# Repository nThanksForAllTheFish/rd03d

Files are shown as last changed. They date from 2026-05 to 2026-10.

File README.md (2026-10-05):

# RD-03D stair radar

A 24 GHz radar in a 3D-printed case watches a staircase and turns the light on before anyone reaches the first step, then off a minute after they are gone. The sensor is an Ai-Thinker RD-03D, the controller a Seeed XIAO ESP32-C6, the automation a four-node Node-RED flow. Nearly all of the firmware, the web chart, the flow and the enclosure CAD were written by an AI agent over four weeks of evenings, with the CAD built by driving a live Fusion 360 session through its scripting API. The write-up below is about how that went, and about the places where the reviewing human earned his keep.

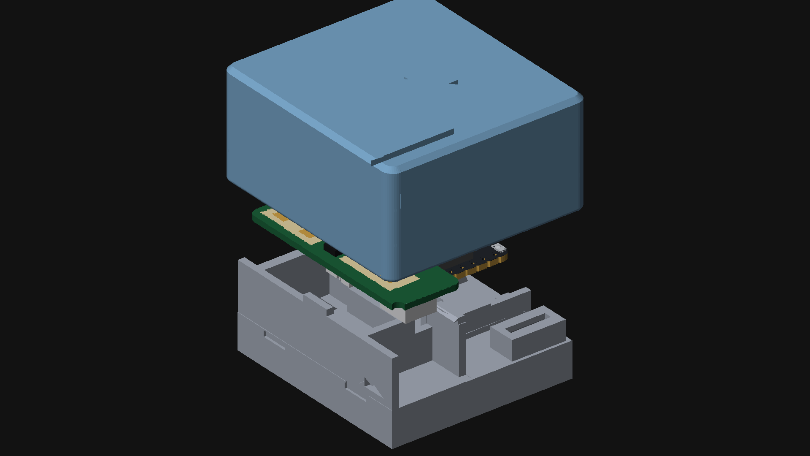
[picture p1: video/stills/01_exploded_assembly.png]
Exploded view: back plate, RD-03D and XIAO, front shell


## What is in this repository

| Path | What it is |
| --- | --- |
| `rd03d_uart/` | ESP-IDF firmware for the XIAO ESP32-C6: radar frame parser, live browser chart over WebSocket, MQTT events, OTA with rollback, station and access-point images. Host-side unit tests in `tests/`. |
| `case/` | The two-part snap-fit case: STLs ready to print, and the numbered Fusion 360 Python scripts that are the actual design, plus the read-only geometric probe harness `90_verify.py`. |
| `node-red/` | The stair-light flow, a validator, and an MQTT acceptance test. |
| `RD03D_RadarChart/` | The original Processing visualiser for the sensor over USB serial, kept for reference. |
| `docs/superpowers/` | The ten dated design specs and implementation plans the agent worked from, in the order they were written. |
| `video/` | The pipeline that synthesised the project video: frame generator, narration, STEP-to-mesh converter, and the rendered figures used below. |

Each of the first three directories has its own README with the details. The rest of this page is the quick start and the story.

## Quick start

Wire the radar to the XIAO: radar TX to D7 (GPIO17), radar RX to D6 (GPIO16), 5 V and GND. The radar UART runs at 256000 baud, 8N1.

Build and flash with ESP-IDF v5.5. The WiFi SSID and password live only in the untracked `sdkconfig`, set through `idf.py menuconfig` under *RD03D Configuration*.

```bash
cd rd03d_uart
idf.py set-target esp32c6
idf.py menuconfig          # RD03D Configuration: WiFi SSID / password, MQTT broker
idf.py build
idf.py -p /dev/cu.usbmodemXXXX flash monitor
```

Open `http://rd03d.local` on the same network for the live chart. After the first USB flash, updates go over WiFi and roll back by themselves if the new image fails to come up within 90 s:

```bash
idf.py build && curl -X POST --data-binary @build/rd03d_uart.bin http://rd03d.local/update
```

For a site where the device cannot join the WiFi, build the access-point image instead. It brings up its own network, `rd03d-radar`, serves the chart at `http://192.168.4.1`, and compiles MQTT out:

```bash
idf.py -B build.ap -D SDKCONFIG=sdkconfig.ap build
```

The station image publishes `rd03d/target/1..3` as `{"x","y","v"}` in millimetres and centimetres per second whenever a target appears or has moved more than 200 mm, `{"gone":true}` when it leaves, and a retained `rd03d/status` of `online` or `offline`. Import `node-red/flows-stair-light.json` into Node-RED, change the relay topic in the node marked *EDIT DEVICE*, tune the zone in the node marked *EDIT ZONE* using the chart, and deploy. `node-red/test_stair_flow.py` exercises the flow with synthetic events.

Print the case in PETG, 0.2 mm layers, no supports, with the shell at high infill so the radome in front of the antennas is solid plastic. Fit the USB-C jack before the boards. The six holes in the back are LEGO Technic pitch, for a ball-joint mount. The full assembly order, including why the jack goes in from the back and is soldered afterwards, is in `case/README.md`.

The host tests need nothing but a C compiler:

```bash
cd rd03d_uart/tests
cc -Wall -Wextra -o test_rd03d test_rd03d.c ../main/rd03d.c && ./test_rd03d
cc -Wall -Wextra -o test_mqtt_throttle test_mqtt_throttle.c ../main/mqtt_throttle.c && ./test_mqtt_throttle
```

## A radar stair light, built with an AI co-engineer

The gadget is a weekend's work for anyone reading this and not worth an article. What is worth an article is that over four weeks of evenings, from the end of August to late September, an AI agent wrote essentially all of the firmware, the web interface, the home-automation flow, and the CAD for the enclosure, and that the CAD was done by driving my own copy of Fusion 360 directly rather than by emitting a file for me to import. My job turned into something closer to a reviewing engineer and lab tech than a designer, and I caught the agent out often enough that the review was not a formality. I think the shape of that collaboration maps directly onto any one-off hardware build: the bracket, the jig, the sensor-in-a-box that most of us design once and never document.

### What got built

The sensor is an Ai-Thinker RD-03D, a 24 GHz FMCW module with one transmit patch pair and a 2×2 receive array that tracks up to three targets and spits out x, y and radial velocity over a 256 kbaud UART, thirty bytes per frame. It is wired to a Seeed XIAO ESP32-C6, a thumbnail-sized RISC-V board with 2.4 GHz WiFi. The firmware is ESP-IDF, about 1,450 lines of C including the host tests. It parses the radar frames, serves a live radar plot in a browser at a local mDNS name over a WebSocket at about 11 Hz, publishes target events over MQTT to a Mosquitto broker, takes over-the-air firmware updates with automatic rollback if a new image fails to come up, and can be built as a second variant that is its own WiFi access point with MQTT compiled out, for places where you cannot put a stray device on the network. A Node-RED flow on a Raspberry Pi subscribes to the target topics, applies a zone filter, holds the light on with a retriggerable 60 s timer and drives a Tasmota relay.

The enclosure is a two-part snap-fit case: an 8 mm back plate carrying the radar bay, the XIAO posts, five cantilever retention clips, a USB-C power jack with its decoupling capacitor cradled inside, and six LEGO Technic pin holes on 8 mm pitch so the whole thing hangs off a Technic ball joint for aim adjustment. The front shell has a thinned radome step over the antennas and a hold-down boss over the XIAO's RF can. It printed in PETG on a 0.6 mm nozzle with no supports, after seven revisions of the plate.

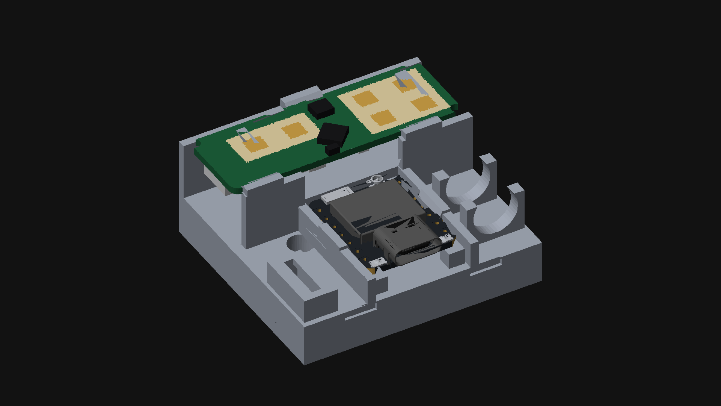
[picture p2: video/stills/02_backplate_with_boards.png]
Back plate with both boards seated


### How the firmware side went

The working pattern was the same for every feature. I described what I wanted in a paragraph. The agent wrote a short design spec, I read it and argued with it, then it wrote a numbered implementation plan and executed it, testing as it went. Ten of those spec-and-plan pairs are in `docs/superpowers/`, dated, and they read like a lab notebook. The UART reader came first, with the frame parser written as plain C and unit-tested on the Mac before it ever touched the board. The WiFi web chart came next, then OTA, then MQTT, then the Node-RED flow, then the access-point variant, each as a branch merged after a hardware check.

The useful discipline here was that the agent insisted on testable seams. The radar parser and the MQTT throttling logic, which decides that a target has to move 200 mm before a new event is worth publishing, are pure functions with nineteen host-side tests between them. The OTA path got a deliberate drill: we flashed an image that was built to fail, watched it boot, fail to bring up its web server inside the 90 s window, and roll itself back to the previous image in about 95 s. The browser-side verification was equally direct. The agent opened the chart in a browser, walked the WebSocket, and read the HUD back to confirm the firmware version it had just flashed.

It also walked into the kind of traps that any of us would have, and had to dig out. Two examples. The ESP-IDF web server does not call your URI handler during a WebSocket handshake, so the client-tracking pattern in the first draft was dead code, and clients had to be enumerated from the server's own list instead. More subtly, the access-point variant kept rolling back after every OTA while USB flashing worked fine. The rollback-cancel was gated on "we have an IP address", and in AP mode no IP event ever fires. The fix was one line. Finding it was an evening. None of this is a criticism of the tool so much as a reminder that it is doing real engineering with the same documentation we have, and the documentation lies in the same places.

### How the CAD side went, which is the part I want you to see

The enclosure was not designed by generating a mesh. Autodesk ships a Model Context Protocol server for Fusion 360, which is a small local HTTP endpoint that lets an agent run Python against the live Fusion API inside your open document. The agent wrote a driver that speaks that protocol, `case/fusion_scripts/run_fusion.py`, then built the case as a sequence of numbered Python scripts: set up user parameters, build the back plate, build the shell, place reference bodies for the two boards, export STLs. About 1,900 lines of Python in all, and those scripts are the design. Every feature in the plate, every clip, ramp, counterbore and wire notch, is a few lines in a script that reads like a construction record, with the dimension and the reason next to each other. When something had to change, the agent edited the script and re-ran it, and Fusion rebuilt the body. I watched it happen in the Fusion window.

Two things about this were new to me. The first is that a scripted design is reviewable in the way code is reviewable. I could read a diff and see that a rib had moved from x 3.0 to x 5.6 and why. Try doing that with a feature tree. The second is that the agent wrote itself a verification harness. The last script in the sequence, `90_verify.py`, is read-only: it probes the finished bodies with point-containment queries, asking Fusion "is there material at this coordinate" at a few dozen points, and asserts that the walls are where the spec says, that the counterbores are open, that the USB jack slot is clear, that a rib is not roofing a LEGO bore. It caught exactly that last one, a capacitor rib placed over a pin hole, before I printed it. That is a unit test for a mechanical part, and I had never seen one.

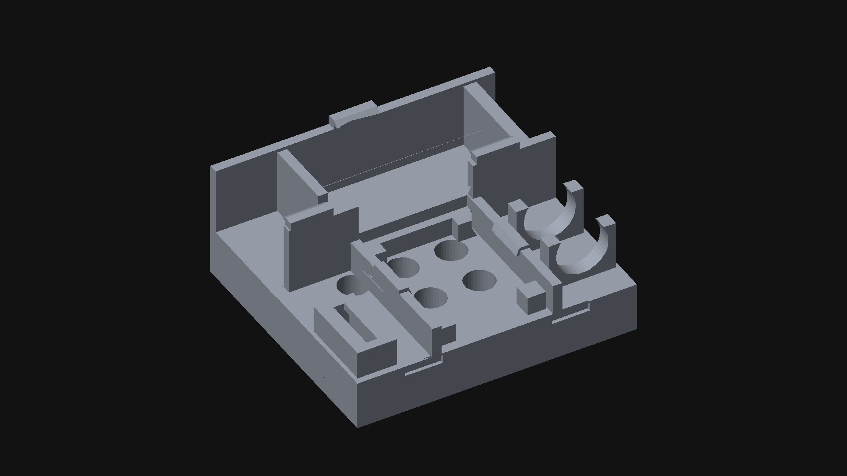
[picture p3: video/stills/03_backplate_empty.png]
Empty back plate: crossbars, clips, jack slot and capacitor cradle


### Where the human earned his keep

The honest part of the story is the list of things the agent got confidently wrong and I caught, usually by holding the printed part or staring at the Fusion model. I am including it because it is the real argument for this way of working: the agent is fast and tireless and does not know what it does not know, and a reviewing engineer who does is the thing that makes the pair better than either alone.

The board was resting on its connector. The agent had sized the crossbars under the radar PCB from the board's overall thickness, which includes a 5-pin connector that protrudes rearward. The bare PCB back is actually 3.8 mm further in. So as designed the radar sat on its connector and nothing else. I spotted that in the Fusion model; the agent then probed the vendor's board model, found two component-free bands, and moved the crossbars to bear on bare PCB with the connector hanging free between them.

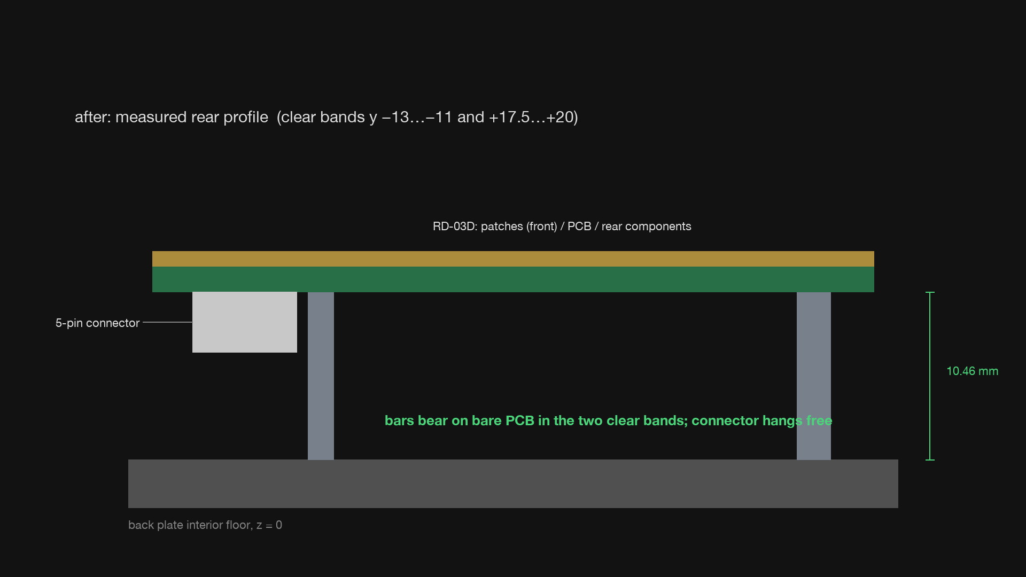
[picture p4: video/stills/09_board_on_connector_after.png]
Before and after: the board on its connector, then on the crossbars


The radome was tuned to the worst possible gap. This one is the physics lesson, and I want to spell it out. At 24 GHz the free-space wavelength is λ = c/f = 12.5 mm. The agent had, several times, assured me the air gap between the antenna face and the inside of the radome was about 1 mm. It had anchored that number on the top of the board's bounding box, which is the tallest IC, not the antenna plane. The true antenna-to-radome gap, after a well-meaning change that moved the window pocket to the inside face, was 3.1 mm. A quarter wavelength is λ/4 = 3.125 mm. A quarter-wave gap is the anti-resonance case: the wave reflected off the radome's inner surface travels an extra half wavelength out and back, picks up the phase flip at the plastic boundary, and arrives back at the antenna in phase with the transmitted wave, which is the maximum possible mismatch. It is the same reason an anti-reflection coating is a quarter wave thick, run backwards. The rule I gave the agent and it then designed to was to keep the gap under λ/10, about 1.25 mm, where the reflected field has not had room to rotate far. The fix brought the radome down to a 1.21 mm gap over both antenna groups, with the plastic in front of them a solid 3.1 mm, and the exterior face stays flat. I would not have caught this from the script. I caught it from a section view.

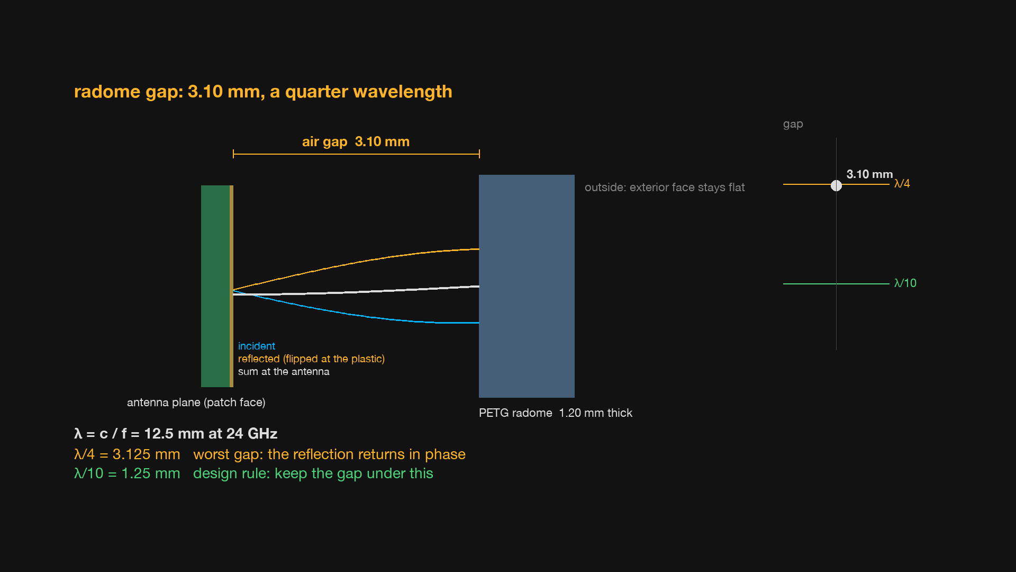
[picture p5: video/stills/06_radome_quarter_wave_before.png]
The radome gap at a quarter wavelength


The antenna was going in sideways. The two receive channels that give the module its angle measurement are spaced across the board's short axis, about λ/2 apart. That means the wide ±60° field of view opens across the board's width, and the beam is narrow along its length. I had assumed the opposite. For a staircase, where the sensor must tell an upstairs approach from a downstairs one, the fan has to be vertical, so the board mounts landscape. This was a fifteen-second conversation once the antenna geometry was on the table, and the kind of thing anyone who has laid out a patch array would catch before coffee.

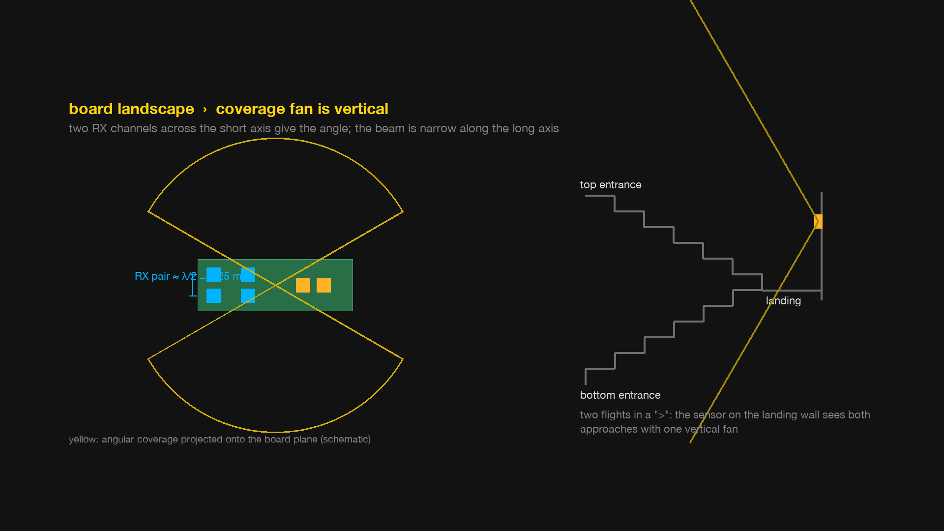
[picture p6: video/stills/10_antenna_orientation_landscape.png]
Antenna orientation: the fan opens across the board's width


The printer disagreed with the design. The first plate design had 0.6 mm fence walls and a shallow tape recess on the back face. I print with a 0.6 mm nozzle, so a 0.6 mm wall is at best one wobbly extrusion, and the recess meant the first layer was a thin rim with nothing in the middle. Both came out. All walls are now at least 1.5 mm, and the back is one flat face. Later the agent designed the XIAO clips as slender slotted fingers with the root trenched below the floor to keep bending strain near two percent in PETG, which is correct and which held the board about as firmly as a wet noodle. The slots and trenches came out and the clip is now a plain stretch of the 1.5 mm wall with a 0.6 mm lip. It takes a firm push to click the board in. That is fine. The agent's analysis was right about strain and wrong about what "holds" means to a thumb.

And the diagnosis that cost an hour: curl to the device's mDNS name hung every time while a browser worked. The device advertises an IPv6 link-local address over mDNS that is not routable from the Mac, curl tries it first and waits out its timeout. Forcing IPv4 fixes it. Not a device fault at all, and the agent and I both chased ghosts in the firmware before checking.

### What this means for your next part

Most of what gets printed in a home shop is a one-off: a bracket for a sensor, a jig to hold a board while you solder it, a mount for a camera, a box for the thing you just built. The loop I ran here, which is describe the part, have the agent build it parametrically in Fusion with a probe harness, print it, hold it, correct it, re-run the script, is the loop we already run with a human at the keyboard, only the keyboard part now takes minutes instead of an afternoon and leaves a reviewable script behind it. A part designed this way comes with its construction rationale and its own geometric self-test, and you, or anyone who forks this repo, can re-run it with a different board outline next year. None of this depends on Fusion. Any CAD package with a scripting API can be driven the same way: FreeCAD and OpenSCAD are scripting-native, Onshape has a REST API, and SolidWorks has a mature COM automation interface that is if anything an easier target than Fusion's.

The firmware side is the same story. A sensor on a serial port that logs to a broker and shows a live plot in a browser is exactly the sort of thing we build for a weekend project and then never document. Here the spec, the plan, the tests and the OTA path came along for free, because the agent will not skip them unless you tell it to.

Three cautions, briefly. First, the agent's confidence is uncorrelated with its correctness on anything it cannot measure, which in CAD is everything. Every print I did without a section view first was a print I did twice. Second, the physics still has to come from somewhere, and in this project it came from me and from the datasheet. The λ/4 mistake would have shipped. Third, treat the scripts, not the live CAD document, as the source of truth, and keep them under version control. The one time I let the agent tune a parameter in the Fusion UI instead of the script, the next re-run of the setup script silently reset it.

## Parts

- Ai-Thinker RD-03D 24 GHz radar module
- Seeed Studio XIAO ESP32-C6
- USB-C receptacle breakout with 5.1 kΩ CC pull-downs, 100 µF capacitor
- Raspberry Pi running Mosquitto and Node-RED
- Tasmota-flashed relay or smart plug
- PETG filament, 0.6 mm nozzle, no supports, shell at high infill so the radome is solid plastic
- Six LEGO Technic pins and a ball-joint arm for mounting

## Video

A synthesised walkthrough of the project, rendered from the STLs, the vendor board models and the real source files in this repository, is on YouTube: https://youtu.be/SwnVpzrGE3c. The video's script, this README and the write-up above were drafted by the AI agent (Claude Code), then reviewed and corrected by the author. The pipeline that produced the video is in `video/`; the board STEP models it uses are third-party downloads and are not redistributed here.

## Licence

Code is MIT (`LICENSE`). The write-up, documents, STL files and figures are CC BY 4.0 (`LICENSE-CC-BY-4.0.md`).

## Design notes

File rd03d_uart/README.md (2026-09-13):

# rd03d_uart

XIAO ESP32-C6 firmware that reads an Ai-Thinker RD-03D 24GHz mmWave radar over
UART1, prints decoded targets to the USB-C serial console, and serves a live
radar chart over WiFi.

The tree builds two images from the same sources:

| | Station (default) | Access point |
| --- | --- | --- |
| WiFi | joins an existing 2.4 GHz WPA2 network | is its own WPA2 access point |
| Chart at | http://rd03d.local | http://192.168.4.1 |
| MQTT | published | compiled out |
| Build dir | `build/` | `build.ap/` |
| Config | `sdkconfig` | `sdkconfig.ap` |

Use the AP image where the device is not allowed onto the local WiFi — a work
site that only admits registered hardware, or anywhere there is no network to
join.

## Wiring

| RD-03D | XIAO ESP32-C6 |
| --- | --- |
| TX | D7 (GPIO17) |
| RX | D6 (GPIO16) |
| 5V | 5V |
| GND | GND |

Radar UART: 256000 baud, 8N1.

## Build & flash

Find the port rather than assuming it — boards enumerate differently, and a
second board plugged into the same Mac will not get the same number:

```bash
ls /dev/cu.usbmodem*
```

With more than one board attached, confirm which is which before flashing.

Station image (joins your WiFi):

```bash
source ~/esp/esp-idf-v5.5/export.sh
idf.py set-target esp32c6   # first time only
idf.py build
idf.py -p /dev/cu.usbmodemXXXX flash monitor
```

Access-point image:

```bash
source ~/esp/esp-idf-v5.5/export.sh
idf.py -B build.ap -D SDKCONFIG=sdkconfig.ap build
idf.py -B build.ap -D SDKCONFIG=sdkconfig.ap -p /dev/cu.usbmodemXXXX flash monitor
```

The two configurations never collide: each keeps its own build directory and
its own config file, so switching between them needs no clean and no
`set-target`.

### The config files hold the credentials, and git does not

`sdkconfig` holds the home/office network SSID and password. `sdkconfig.ap`
holds the SoftAP PSK. **Both are untracked and deliberately gitignored, so
neither is in any commit — delete one and the credentials in it are gone.**
Keep a copy somewhere outside the repo before doing anything drastic, and
never `rm` them to "get a clean build" (use a different `-B` directory
instead). Everything else in them regenerates from `idf.py menuconfig`
(*RD03D Configuration*); the passwords do not.

## Output

One line per radar frame (up to 3 targets), plus link stats every 5 s:

```
T1: x=-123mm y=456mm v=-12cm/s | T2: --- | T3: ---
I (5210) rd03d: link stats: dropped=0 bad_frames=0
```

`dropped` counts parser resync bytes only (not any UART driver-level loss);
`bad_frames` counts frames with a corrupt tail. Both should stay flat while a
monitor is attached.

Note that the USB-Serial-JTAG console does not reset the board when you attach,
so connecting late shows radar frames but no boot banner. Reset the board (or
use `idf.py monitor`, which resets for you) to see the startup log.

## Web UI

Either image serves the same live chart: targets on an XY plot with trails,
plus link stats.

- Data path: `GET /ws` WebSocket pushes one JSON message per radar frame,
  e.g. `{"t":[{"x":-551,"y":550,"v":0},null,null],"dropped":0,"bad":0}`
  (x/y in mm, v in cm/s, absent targets `null`).
- At boot the firmware puts the radar in multi-target mode itself; viewers
  never send radar commands.
- Untethered use: power the XIAO from a USB power bank; the USB console is
  optional diagnostics only.

### Station image

Joins the network configured in `idf.py menuconfig` (*RD03D Configuration* →
SSID/password, stored only in `sdkconfig`; 2.4 GHz WPA2 only). Open
**http://rd03d.local** from any browser on that network.

### Access-point image

The XIAO brings up its own network on boot; nothing else is required, and
there is no router, DHCP lease, or broker involved.

- SSID **`rd03d-radar`**. The PSK is not written down here — this file is
  tracked in git. It lives in `sdkconfig.ap` as `RD03D_AP_PASSWORD`, visible
  through `idf.py -B build.ap -D SDKCONFIG=sdkconfig.ap menuconfig`.
- Once joined, open **http://192.168.4.1**. mDNS is also registered, so
  **http://rd03d.local** usually works too — but 192.168.4.1 is the address
  that always works, so reach for it first when something seems wrong.
- **Joining the AP takes the laptop off its normal WiFi**, since a client can
  hold only one association at a time. Run the intranet over ethernet
  alongside it; macOS will use the wired interface for everything that is not
  192.168.4.x.
- The boot log confirms the AP is up:
  `wifi_link: softap up, ssid=rd03d-radar channel=6, http://192.168.4.1`

If the link feels slow or drops, **`RD03D_AP_CHANNEL` is the first knob to
turn** (*RD03D Configuration* → SoftAP 2.4 GHz channel, default 6). Offices
are usually congested on channels 1 and 11, which is where most access points
land by default; 6 avoids the worst of it, and the other non-overlapping
choices are worth trying before suspecting the firmware.

## OTA firmware updates

The device carries two firmware slots with automatic rollback — a bad update
reverts to the previous firmware by itself. To become permanent, a new image
must bring the WiFi link up *and* have the web server running within 90 s.
That check is mode-independent: in station mode the link counts as up once
the device has an IP, in AP mode once the SoftAP has started.

Update over WiFi (no USB needed) — station image:

```bash
idf.py build
curl -X POST --data-binary @build/rd03d_uart.bin http://rd03d.local/update
```

Access-point image, with the laptop joined to `rd03d-radar`:

```bash
idf.py -B build.ap -D SDKCONFIG=sdkconfig.ap build
curl -X POST --data-binary @build.ap/rd03d_uart.bin http://192.168.4.1/update
```

Push the image built from the matching config — flashing a station image over
the AP link works, but the device then joins your WiFi and disappears from
192.168.4.1, and recovering it needs USB. Either endpoint also takes a browser
upload at `/update`. The running version shows at `/version`, on the update
page, and in the chart HUD; confirm it still reports the *new* commit a couple
of minutes after an update, which is what proves the image was validated
rather than silently rolled back.

USB flashing is only needed for first-time setup and for switching an already
flashed board between the two images (partition table changes require
`idf.py erase-flash flash`).

**After any OTA, use the full `idf.py flash`, never `idf.py app-flash` alone.**
`app-flash` writes only the app partition; it leaves otadata pointing at
whichever slot the last OTA selected, so the bootloader keeps starting the old
image and the board looks like the flash silently did nothing. The full
`flash` rewrites otadata along with the app. If you have already used
`app-flash`, follow it with `idf.py erase-otadata`.

## MQTT events

**Station image only.** MQTT is compiled out of the AP image (`RD03D_ENABLE_MQTT`
is off in `sdkconfig.ap`): the esp-mqtt client is not linked in, no broker is
needed, and none is contacted — an AP-mode device has no route to one anyway.
The AP image is ~140 KB smaller as a result.

The station image publishes to the broker configured in `idf.py menuconfig`
(*RD03D Configuration*, default `iotstack.local:1883`, anonymous):

- `rd03d/target/1..3` — `{"x":-551,"y":550,"v":0}` when that target first
  appears or has moved ≥ the configured distance (default 200 mm) since the
  last published position; `{"gone":true}` once when it disappears.
  QoS 0, not retained.
- `rd03d/status` — retained `online`/`offline` (Last-Will), so consumers
  (e.g. Node-RED) always know whether the sensor is alive.

While the broker is unreachable nothing is queued; on (re)connect the device
republishes `online` and the current position of every present target.
The broker hostname is resolved (via mDNS for `.local` names) once at boot —
if the broker's IP changes, reboot the XIAO (or just re-upload firmware).

## Host-side tests

These compile the parser and throttle sources directly on the host, so they
are unaffected by which image you are building:

```bash
cd tests
cc -Wall -Wextra -o test_rd03d test_rd03d.c ../main/rd03d.c && ./test_rd03d
cc -Wall -Wextra -o test_mqtt_throttle test_mqtt_throttle.c ../main/mqtt_throttle.c && ./test_mqtt_throttle
```

Frame format and sign-magnitude decoding match
`../RD03D_RadarChart/README.md` (Processing visualizer for the same sensor).

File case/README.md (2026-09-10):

# RD-03D + XIAO ESP32-C6 Case

Two-part snap-fit case designed natively in Fusion 360 (built via its MCP
API — the numbered scripts in `fusion_scripts/` are the construction record).
The living design is in your Fusion; save it to your own project.

## Parts

- `rd03d_case_back.stl` — back plate (8 mm thick): radar bay left, XIAO
  posts right, with five snap retention clips (three on the radar's
  ±X fence walls, one on each of the XIAO's ±Y walls);
  six LEGO Technic pin holes (8 mm pitch, counterbored on the **rear face
  only**) through the back for pin/ball-pin mounting; and a **USB-C power
  jack**, with a capacitor cradle and wire notches inside. Apart from the
  jack's mouth — which sits flush in it — the rear face is flat (great
  first layer; tape sticks directly to it), and so is the interior floor,
  which carries no counterbores.
- `rd03d_case_shell.stl` — front shell: a radome step that brings the
  front wall down to 1.2 mm in front of the antennas (solid 3.1 mm of
  plastic there, exterior face still perfectly flat), a hold-down boss
  over the XIAO, four snap bumps engage the plate's edge grooves. Its
  side walls are unbroken: the old side USB notch is **gone** — see the
  USB-C base jack section below.

## Printing

**PETG preferred** — the five retention clips are live springs and PLA is
brittle enough to snap one on the first insertion. 0.4–0.6 mm nozzle,
0.2 mm layers, no supports.
Back plate: print flat (back face down). Shell: print open-side-up.
Print the **shell at high or solid infill** (≥50 %, ideally 100 % over the
front wall): the 3.1 mm radome in front of the antennas should be
homogeneous plastic — sparse infill puts a patchwork of air pockets in the
radar's beam path and scatters it unpredictably.
Exterior edges are filleted/chamfered for comfort; the front face's 1 mm
chamfer prints cleanly bed-side.

## Assembly

Fit the USB-C power jack **first** — see the next section. It goes in from
the **back face**, tail first, and it is soldered *after* it is seated, so
you want the empty bay to work in: doing it after the boards are clipped
down means holding an iron over them.

1. Wire the boards (radar TX→D7, RX→D6, 5V, GND), then **press each board
   straight down until it clicks under its retention clips** — three for
   the radar, two for the XIAO. Each clip's tapered face cams open as the
   board's edge goes past and springs back over it; to remove a board,
   push the clips outward with a fingernail. Seat the RD-03D patch-side
   out, the XIAO on its posts with its own USB-C connector at the +X end
   (that port no longer reaches daylight — power comes in through the base
   jack instead). The radar is still Y-loose until the shell closes;
   that's normal.
   - **Insertion tip:** don't press a board down flat. Tuck one long edge
     under its clip(s) first, then rock/press the opposite edge down —
     you then only flex the clips on one side at a time, which roughly
     halves the force and keeps you from bowing the PCB.
   - Radar clips: 0.6 mm of grab per side, **three** of them — one on the
     −X fence wall at mid-height (y ≈ 0, over the radar IC), and two on
     the +X wall, at y ≈ −17 and y ≈ +13.5. The +X wall cannot carry a
     clip at y ≈ 0 because the XIAO board crosses it there, so its share
     is split into two clips, one behind each antenna group. These three
     have **no relief slots**: the lip sits 11.8 mm above the plate, so
     the 1.5 mm fence wall is already a long enough cantilever to give up
     the 0.6 mm of deflection at about 1 % surface strain. Slotting it
     would only have weakened the wall's real job, which is holding the
     radar board laterally.
   - XIAO clips: 0.34 mm of grab per side, on the ±Y fence walls, and as
     of **2026-09-10 these have no relief slots and no root trenches
     either** — the wall is continuous. The first printed version *was*
     slotted, with a 1.2 mm trench either side sinking the cantilever
     root below the floor, all to keep bending strain low on a short
     lever. It held the board far too weakly in the hand ("very wimpy"),
     so the slots and trenches came out. What is left is a 7 mm stretch
     of the plain 1.5 mm fence wall, raised locally to 5.6 mm, carrying
     the same 0.60 mm lip with its underside 0.10 mm above the board.
     Anchored along its whole base and continuous with the wall either
     side, it is far stiffer than the old isolated finger and holds much
     harder. **The trade is insertion force** — expect a firm push to
     click the XIAO in, and use a fingernail or a spudger on the lip to
     get it out. The rock-one-edge-in tip above matters more here than
     anywhere else. The 7 × 7 mm boss on the inside of the shell's front
     wall, which comes down onto the XIAO's RF shield can, still backs
     them up once the lid is on.
   The radar lands on two crossbars that bear on the bare PCB, in the two
   component-free bands across the board's back — its 5-pin connector
   hangs free in the space between them, so don't force the board down
   onto anything.
2. Snap the shell on (bumps click into the plate grooves). There is no
   longer a USB notch to hook a fingernail into, so to get the lid back
   off, work a thin plastic spudger or guitar pick into the parting seam
   at a corner and walk it along until the bumps let go.
3. Mounting: push Technic pins / ball-pins into the six back holes
   (8 mm LEGO pitch: 1×4 column + 1×2 column); a ball-and-socket arm
   gives adjustable aim. Or stick VHB tape directly to the flat back
   if you prefer adhesive mounting.

## USB-C base jack (added 2026-09-09)

Power comes in through a USB-C jack in the back plate — the LEGO-mount face.
The XIAO's own USB-C is **no longer reachable with the case closed**: the
shell's side notch is gone. Serial console and USB reflash need the lid
unclipped; OTA over WiFi is unaffected.

**Fit the CC pulldowns first.** The jack needs 5.1 kOhm from CC1 and from CC2
to GND. Without them a modern USB-C charger never enables VBUS — but a
USB-A-to-C cable works either way, because A ports always have VBUS live,
which makes this failure very confusing to diagnose.

**Assembly order — seat the jack from the BACK, and solder it afterwards.**

The jack goes in the way a plug does: from outside, through the back face.
It cannot go in from the inside, and it must not be pre-soldered.

> **Why not from inside, mouth first?** The two seating ramps narrow the
> collar bore to **1.82 mm** from z 3.38 upward, and the jack's metal shell
> is **3.17 mm** thick. Pushing the shell down through that channel means
> levering a 3.17 mm metal part against two 1.5 mm PETG collar walls — they
> break before it passes. Only the thin PCB tail fits the 1.82 mm channel,
> which is exactly what the ramps are for.

1. **Seat the jack from the back face, tail first.** The PCB tail passes up
   through the slot and out through the 1.82 mm channel between the ramps;
   the metal shell follows into the full 3.42 mm slot and wedges to a stop
   on the ramps, with the mouth flush at the back face. About 6.4 mm of the
   body then stands above the interior floor, and the tail's solder pads
   end up at z ≈ 6.42 — clear above the 4.5 mm collar, which is the whole
   reason this order works.
2. **Plug a cable in and confirm it bottoms out properly** — while the jack
   is still free to be pushed back out and re-seated.
3. **Then solder** the two supply wires to the tail's VBUS and GND pads.
   They are standing exposed above the collar, so the iron reaches them
   easily with the jack in place.
4. **Then two dabs of epoxy** in the collar. This is the only thing
   resisting pull-out — the connector has no rearward-facing surface for a
   printed feature to catch, so the ramps take the push-in load and the glue
   takes the rest.

**Capacitor.** The 100 uF electrolytic lies on its side in the two-rib cradle
in the +Y band, lead end toward +X. It snaps down past its equator; no lid
feature holds it.

**RD-03D connector cable (added 2026-09-10).** The connector sits in a pocket
sealed on three sides by the two bay walls and by crossbar A, the rib that
carries the board's rear face. Crossbar A has a 4.0 x 3.5 mm notch in its
TOP, hard against the +X wall, so the cable can get out:

1. Plug the cable in, then lay the four wires through the notch in the top of
   crossbar A, hugging the +X wall. They stay at connector height (its
   underside is z 6.70) rather than diving to the floor, and once the radar
   board is clipped down they are captured between the notch floor and the
   board's rear face, so they cannot wander.
2. Run them +Y along that wall, under the radar board (there is 10.46 mm of
   headroom), to the step-4b notch at |y| < 9.4.
3. Cross the wall there. That notch is open from z 3 to the ceiling, i.e.
   ABOVE the XIAO, whose top face is at 4.20 - so the wires land on top of
   the board and both long edges are in reach. That matters: D6 is on the +Y
   edge and D7 on the -Y edge, so a route arriving from one side would
   strand one of them.

Do this before clipping the radar board down. There is also a 2.15 mm notch
in the -Y corner of the +X wall if you would rather take 5V/GND out to the
-Y band, where the jack and capacitor already are.

**Wire routes.**

- Jack to XIAO: out of the collar and straight over the top of the -Y fence
  bar onto the 5V and GND pads. The bar tops out at z 5.00 and the pads sit
  at 4.20, so it is an 0.8 mm climb with ~9 mm of headroom to the shell.
  (There were wire notches here until 2026-09-10; they were deleted because
  the clip rework made wall continuity matter more than the 0.8 mm.)
- **Solder on the top face only, and mind the clip lips.** The lips overhang
  the board's ±Y edges by 0.34 mm with just 0.10 mm of clearance above it,
  over x 4.5..11.5. A solder joint on an edge pad in that span will foul
  one. The four pads you need are all outside it — 5V ≈ x 14.9, GND ≈ 12.4,
  D6 and D7 ≈ −0.4 — but GND clears the finger's end by under a millimetre,
  so check it before you commit to a fat joint.
- Capacitor to the 5V rail: **over a fence bar.**
  There is *no* channel round the +X end of the XIAO fence — both ±Y fence
  bars run the full width of the plate, out to the edge at x 20.85. (Only the
  *board* stops short, at x 19.23; the wall beside it does not.) So take the
  leads either **over the top of a bar** — they are 5 mm tall in a 14 mm
  cavity, leaving about 9 mm of headroom — or **through the ±Y wire notches
  and across the bay above the XIAO**. Join at the jack pads or at the XIAO
  pads, whichever is tidier.

**Plug clearance.** The constraint is the plug overmold's **thickness** — its
short dimension, which runs along **Y**, across the slot's short axis. The
slot is centred at y −19.0 and the shell's skirt puts an inner rim face at
y −23.0 (at z −8), so an overmold thicker than about **8 mm** cannot reach the
mouth. The overmold's *width* runs along the slot's long axis (X) and is
unconstrained. Measure the plug **across its thin dimension**, not its wide
one, and if it is over ~8 mm use a right-angle or slim plug.
(There is no LEGO hole at (8.95, −12) — the x 8.95 column carries holes only
at y ±4. The six centres are (0.95, ±12), (0.95, ±4) and (8.95, ±4).)

## Tweaking fit

Open the design in Fusion → Modify → Change Parameters. `boardClear`,
`rimGap`, and `snapBump` are the fit-critical ones; `legoHole` is the
Technic pin hole diameter (tune ±0.1 mm if pins are too tight/loose after
a test print). No metal or foil in front of the radar, ever.
The retention clips and the radome step are local constants inside
`fusion_scripts/02_backplate.py` and `03_shell.py` (grab amounts, lip
heights, `RADOME_Z0`), not user parameters — edit them there and re-run
those two scripts.
The eight `usbJack*` / `cap*` parameters are created by `02_backplate.py`,
not by `01_setup.py`, so they only exist once that script has run.
Re-export STLs after edits (File → 3D Print, or re-run
`fusion_scripts/05_export.py` via `run_fusion.py`).
`fusion_scripts/90_verify.py` is a read-only probe harness that asserts the
jack, cradle, notches, clips and the absent shell notch with
`pointContainment`; run it after any change and expect `VERIFY OK`.

## Design notes

- All free-standing printed walls are ≥1.5 mm (0.6 mm-nozzle friendly); the shell's radar ribs and snap bumps are thinner but are wall-attached, so they print as local wall thickening. The radar's side
  (Y) restraint comes from two ribs inside the shell, so the radar sits
  loose in Y until the lid snaps on — normal.
- **Antenna gap (corrected 2026-09-08).** The RD-03D's patch plane — the
  front face of its PCB — sits at z = 11.70 mm; the shell's front wall
  runs 14.00–16.00. That left a **3.10 mm air gap** in front of the
  patches, which at 24 GHz (λ = 12.5 mm) is almost exactly λ/4 = 3.125 mm:
  the worst possible spacing, because a quarter-wave air layer acts as an
  impedance transformer and the reflection off the plastic returns to the
  patches in phase. Thinning the wall to 1.2 mm (the old "window pockets")
  made it worse, not better — it pushed the plastic *further away*, to
  14.80. The wall is now stepped **down** to z = 12.90 over the two
  antenna zones, so the gap is **1.20 mm ≈ λ/10** and the plastic there is
  a solid 3.10 mm (12.90–16.00). The exterior face is untouched and still
  perfectly flat.
  The 3 mm band over the radar IC (y −4…+4) stays at 14.00: the IC
  protrudes to 12.95 and needs the room (1.05 mm), and the band doubles as
  a stiffening rib for the panel.
  For the record: the "1 mm gap" quoted in the original design was never
  the antenna gap — it was **IC-to-wall clearance** (board overall front
  extent 13.0 vs the wall at 14.0), and the patch plane is 1.3 mm behind
  the IC's tip.
- `windowT` (1.2 mm) is now unused by the antenna zones; it survives as a
  parameter only.
- There is no wire channel between the bays (the boards sit 0.7 mm apart);
  route the four jumpers over the notched fence wall between the bays
  (cut down to 3 mm height there for exactly this).
- Board seating (fixed 2026-09-07): the radar's two crossbar supports now
  top out at 10.46 mm, the measured rear face of its bare PCB, and sit in
  the two full-width component-free bands (y −12.8…−11.2 and
  y +17.7…+19.8). Previously both bars were cut to 6.65 mm — the board's
  total thickness including the rear connector — so the +Y bar missed the
  board by 3.85 mm and the −Y bar was the only support, resting on the
  connector; the board could rock on it. The board's resting height is
  unchanged (patch face still 1 mm behind the front inner wall), so the
  RF geometry is the same.
- The XIAO is held on its posts by a boss on the shell's inner front
  face, landing 0.2 mm above the RF shield can and clear of the USB-C
  connector.
- **Retention clips (2026-09-08, revised 2026-09-09 and 2026-09-10).**
  Each lip's flat
  underside sits 0.10 mm above its board's face (radar 11.80 vs 11.70;
  XIAO 4.30 vs 4.20), so the clips do not preload the boards at rest —
  they only bear if a board tries to lift. That float is deliberate: a
  permanently strained PETG finger would creep. Radar clips are three
  7 mm lip bands on the full-thickness (1.5 mm) fence walls, tops at
  12.50 (−X, under the shell's 14.00 IC band) and 12.30 (both +X, under
  the 12.90 radome zones); the two XIAO clips are the same idea at 7 mm
  wide on the ±Y walls, with a 0.34 mm grab rather than 0.60 mm because
  their board edge is only 4.2 mm up. All five are now lip bands on
  continuous walls — no slots, no trenches anywhere (see below).
  Insertion deflection is ~0.6 mm (radar) and ~0.34 mm (XIAO). Each lip's
  0.6–0.85 mm flat underside is a small unsupported overhang printing
  back-face-down; that is expected and bridges fine at 0.2 mm layers.
  PETG still matters: these are stiff walls being flexed, and PLA is
  brittle enough to crack one.
- **Why the radar clips have no relief slots (2026-09-09).** The radar lip
  is 11.8 mm above the plate. Treating the 1.5 mm wall as a cantilever of
  that length, the 0.6 mm of tip deflection needed to clear the board edge
  works out at ≈1 % peak surface strain — a quarter of PETG's yield — for
  of order 12 N at the lip. So the wall flexes enough unaided, and the
  slots that used to isolate each finger were pure cost: they cut into the
  wall that restrains the radar board sideways. Removing them also freed
  the budget for a third clip.
- **The XIAO clips lost their slots and trenches too (2026-09-10) — the
  one change here driven by a printed part rather than a calculation.**
  Through 2026-09-09 the XIAO clips kept 0.7 mm relief slots at each end
  of the finger and a 1.2 × 1.5 mm trench either side that dropped the
  cantilever root to z = −1.5, lengthening the lever from 4.30 to 5.80 mm
  and holding peak bending strain to ≈2.3 %. The reasoning was sound and
  the arithmetic was right, and it optimised for the wrong thing: the
  printed clips were *very wimpy — barely holding the board in*. Strain
  was never the binding constraint; retention was.

  Slots and trenches are gone. Each XIAO clip is now a 7 mm stretch
  (x 4.5…11.5) of the continuous 1.5 mm fence wall, raised locally to
  5.6 mm, carrying the same 0.60 mm lip with its flat underside at
  z 4.30 — 0.10 mm over the XIAO's 4.20 mm top face — for 0.34 mm of grab
  per side. The lip is deliberately unchanged; the user declined a lip
  change, and 0.6 mm is what a 0.6 mm nozzle resolves cleanly anyway.

  No strain or force figure is quoted for the new arrangement, on purpose.
  The old numbers modelled an isolated end-loaded cantilever; this wall is
  anchored along its entire base and continuous with its neighbours out to
  the plate edge, which is a different problem, and any figure put on it
  here would be invented precision. Qualitatively it is much stiffer and
  holds much better, **and the trade is insertion force** — it takes a
  firm push to seat the board and a fingernail or spudger to release it.
- **Keeping the six Technic bores usable (2026-09-09, final review).** Two
  separate features had crept over the LEGO holes at (0.95, ±12), both while
  the *stated* clearance check only looked at the clip trenches:
  - The capacitor cradle's ribs were at x 3.0 and 12.8. The x = 3.0 rib
    (footprint x 2.40…3.60) sat over the bore, which reaches x 3.40 — a
    1.00 mm overlap across 3.20 mm of y, roofing about 11 % of that bore's
    interior mouth for the rib's full 8 mm height. A Technic pin pushed in
    from the back would have bottomed out on it, and you would only have
    found out after printing. The ribs moved to **x 5.0 and 14.8** — same
    9.8 mm span, so the capacitor sits identically (just centred at x 9.9
    instead of 7.9) — putting the rib edge 1.00 mm clear of the bore.
  - The XIAO clip slots, once they were taken down to z = −1.5, passed
    within **0.431 mm** of the same bore — thinner than a 0.6 mm nozzle can
    lay down, so the slicer would simply have dropped the web. They were
    narrowed from 1.0 mm to 0.7 mm to restore a 0.70 mm web. *(Moot since
    2026-09-10: the slots are gone entirely, and with them this hazard. The
    lesson is not moot — any future feature taken below z = 0 near x 3…4,
    y ±10…12 has to be checked against these bores on its own, not by
    inheriting some other feature's clearance.)*

  The `x = 5.0` rib no longer overlaps anything below the floor either,
  since the trench it used to cross in plan was deleted with the slots.
  `90_verify.py` probes all six bores (centre **and** ±1.5 mm in x, at
  z = 0.5) so nothing can roof one again.
- **Interior LEGO counterbores deleted (2026-09-09).** The six Technic
  bores keep their rear counterbore and rear entry chamfer but no longer
  have one on the inside — a pin only ever enters from the back — so the
  interior floor is flat and the bays gained a little usable depth.
- Caution: re-running `fusion_scripts/01_setup.py` resets ALL user
  parameters to the repo defaults, overwriting any tuning you did in
  Fusion's Change Parameters dialog.
- If the lid snaps on too hard/soft, tune the `snapBump` user parameter
  (0.4-0.6 mm) and reprint the shell only.

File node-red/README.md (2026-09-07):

# Stair Light Node-RED Flow

Turns the staircase light on when the rd03d radar sees a target inside a
zone, and off 60 s after the last in-zone activity. Built-in nodes only.

## Import

1. Open your Node-RED editor.
2. Menu (☰) → **Import** → select `flows-stair-light.json` (or paste its
   contents) → Import → **Deploy**.

## Configure (3 edit points)

1. **Broker** — the flow ships with an `iotstack` broker config node
   (`iotstack.local:1883`, anonymous). If your Node-RED already has a broker
   config for the same server, you can repoint the three MQTT nodes at it
   instead.
2. **Device topic** — double-click *"to Tasmota topic (EDIT DEVICE)"* and
   replace `stairlight` in `cmnd/stairlight/POWER` with your relay's topic.
3. **Zone** — double-click *"zone filter (EDIT ZONE)"* and set the four
   `ZONE` numbers (mm). Tune them with the walk test below.

## Zone tuning walk test

1. Open the radar chart (`http://rd03d.local`) next to the Node-RED debug
   sidebar.
2. Walk to each spot where the light SHOULD trigger (bottom approach, top
   landing) and read your x/y off the chart HUD.
3. Set `ZONE` so those spots are inside and pass-by areas are outside;
   Deploy; walk again and confirm *"in-zone events"* fires only where you
   want it.

## Test without walking

- The **force ON / force OFF** inject buttons drive the relay directly.
- `test_stair_flow.py` publishes synthetic radar events and watches the
  light topic (run it while the radar's view is quiet):

  `python3 test_stair_flow.py [broker] [light-topic] [--wait-off]`
  (arguments are positional; `--wait-off` may appear anywhere)

  Run it while the radar's view is quiet — real in-zone motion breaks the
  out-of-zone check and extends the hold.

## Behavior notes

- Any in-zone target (any of the 3 tracking slots) keeps the light on; the
  60 s hold restarts on each event.
- `{"gone":true}` and radar silence are both simply inactivity — the hold
  timer is the single source of truth for turning off.
- `rd03d/status` appears in the debug sidebar for sensor health but never
  drives the light: if the sensor dies while the light is on, the hold
  expires and the light turns off on its own.
- After a Deploy or Node-RED restart during an active hold, the timer is
  lost: a lit light stays lit until the next occupancy episode ends. If that
  bothers you, press **force OFF** after deploying.
- The force buttons are test aids, not overrides: **force OFF** during an
  active occupancy stays off until the current episode ends (radar activity
  only extends the running hold, it doesn't re-send ON), and a **force ON**
  is cancelled by the episode's eventual OFF.
- The *only changes* (rbe) node is belt-and-suspenders — the trigger already
  alternates ON/OFF strictly. Don't reconfigure it to "per topic" mode; that
  can swallow legitimate ONs.

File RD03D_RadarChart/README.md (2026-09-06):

# RD-03D Radar Chart Sketch

> **Note:** for WiFi viewing, the `../rd03d_uart` firmware now serves its own
> live chart at http://rd03d.local — no Processing needed. This sketch remains
> useful for direct USB-serial connections to the radar.

This Processing sketch reads serial data and renders radar detections on a polar chart.

## How to use

1. Open Processing.
2. Open the sketch folder `RD03D_RadarChart`.
3. Open `RD03D_RadarChart.pde`.
4. Set `serialPortName` if you do not want to use the first available serial port.
5. Set `baudRate` to the correct RD-03D UART baud.
6. Run the sketch.

## Packet format

The sketch parses a binary RD-03D frame using the provided example capture.

Assumed packet structure (30 bytes):

| Byte | Value | Description |
| --- | --- | --- |
| 0 | `0xAA` | Frame header start |
| 1 | `0xFF` | Frame header next |
| 2 | `0x03` | Packet type low byte |
| 3 | `0x00` | Packet type high byte |
| 4-11 | Target 1 block | X1, Y1, velocity, reserved, resolution |
| 12-19 | Target 2 block | X2, Y2, velocity, reserved, resolution |
| 20-27 | Target 3 block | X3, Y3, velocity, reserved, resolution |
| 28 | `0x55` | Frame tail start |
| 29 | `0xCC` | Frame tail end |

### Target block layout

For each target block:

| Byte offset | Field | Description |
| --- | --- | --- |
| 0-1 | `X` | X coordinate, special signed magnitude encoding |
| 2-3 | `Y` | Y coordinate, special signed magnitude encoding |
| 4-5 | `Velocity` | Velocity in cm/s, special signed magnitude encoding |
| 6-7 | `Resolution` | Resolution in mm, little-endian |

### Field interpretation

- `X`, `Y`: 16-bit signed magnitude values in millimeters.
  - The MSB of the high byte is the sign bit.
  - The remaining 15 bits are the absolute magnitude.
  - This is not two's complement.
- `Velocity`: 16-bit signed magnitude value in cm/s.
- `Resolution`: 16-bit little-endian value in millimeters.
- `VALID`: 1 if X or Y is nonzero, else 0.

## Customizing the parser

If your RD-03D packet structure differs:

1. Open `RD03D_RadarChart.pde`.
2. Update `parseBinaryPacket(byte[] packet)`.
3. Adjust `rangeUnitScale` and `velocityUnitScale` to match your sensor units.

## Notes

- The display renders a polar radar grid with configurable FOV and maximum range.
- Detections are drawn as points with a velocity vector overlay.
- The HUD shows packet counts and parse errors for debugging.

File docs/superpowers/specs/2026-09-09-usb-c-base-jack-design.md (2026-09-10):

# USB-C Base Jack, Capacitor Cradle and Wire Routing — Design

**Date:** 2026-09-09
**Applies to:** the live Fusion 360 document `rd-03d_case`, built by
`case/fusion_scripts/02_backplate.py` and `03_shell.py` via the MCP driver.
**Supersedes:** the shell's side USB notch (deleted here) and the XIAO clip
finger geometry set on 2026-09-08.

## Goal

Power the node through a USB-C jack in the back plate — the LEGO-mount face —
instead of through the XIAO's own connector, give the user's 100 uF bulk
capacitor a defined home, and route both to the XIAO's 5V/GND pads. Delete the
shell's side USB notch, which the base jack replaces entirely.

## Measured inputs

**Jack** (user's part, calipers, 2026-09-09):

| dimension | value |
|---|---|
| overall length | 14.42 mm |
| metal shell length | 10.58 mm |
| PCB tail length | 5.50 mm (overlaps the shell by 1.66 mm) |
| widest section (PCB) | 9.08 mm |
| thickness | 3.17 mm |

The PCB tail therefore begins 8.92 mm back from the mouth. With the mouth flush
at the back face (z = -8) the tail's leading edge is at z = +0.92 — **above the
interior floor**, so the plate's through-slot only ever contains the metal
shell. Solder pads are on the tail's outer face at its far end.

**Capacitor:** 100 uF electrolytic, 12.0 mm tall, 8.2 mm diameter, radial
leads from one end.

**XIAO 5V/GND:** user-confirmed on the same long edge as D7, at the end nearest
the XIAO's own USB-C — i.e. the **+X end** of one long edge. The standard
top-view pinout puts that edge at **-Y** in case coordinates (x 14…18,
y -8.89, z 4.2). The design does not depend on this: the fence notch is cut in
**both** ±Y walls, so a mirrored board costs nothing.

## Decision: through-slot with an internal seating ramp

The user selected "Option B" (jack fully recessed, captured against a plate
shelf) before the part was measured. **B does not survive the measurements** and
is not what is built here:

- B's advertised strength — the plate shelf taking pull-out load — does not
  exist. At the mouth end this connector is a plain box with no flange. Its only
  step (shell to PCB, 8.92 mm back) faces *inward*: it resists the plug being
  pushed in, not the jack being pulled out.
- "Nothing protrudes" is geometrically impossible: the part is 14.42 mm long,
  the plate is 8 mm and the interior cavity is 14.0 mm. Any plate left between
  plug and receptacle also steals insertion depth from a 6.5 mm plug shell.

What is built instead keeps B's ledge idea but puts it on the inside, and leaves
the back face flatter than B would have (no overmold relief pocket needed,
because the mouth is flush).

## Geometry

All values in mm, in the existing document frame: plate spans x ±20.85,
y ±22.85, z -8…0; interior cavity ceiling z = 14.

### 1. Jack slot and collar (`02_backplate.py`, new step)

- **Through-slot** `usbJackW + usbJackClear` x `usbJackT + usbJackClear`
  = **9.33 x 3.42**, z -8…0, centred at **(x 13.6, y -19.0)**.
  Long axis along X. 0.5 mm chamfer on the back face so the plug finds it.
- **Collar**: closed four-wall box, 1.5 mm walls, interior matching the slot,
  z 0…4.5. Outer extent x 7.435…19.765, y -22.21…-15.79.
- **Seating ramps**: on both ±Y collar walls, a 45° ramp rising inward 0.8 mm
  from **z = 2.58** (= `usbShellL - backT`) to z = 3.38. The shell's rear edge
  wedges symmetrically into the pair and stops there. Above the ramps a
  **1.82 mm** channel guides the PCB tail.
- The tail's far end lands at z = 6.42, clear above the 4.5 mm collar, so the
  pads stay reachable with an iron after the jack is seated.

Why ramps rather than a flat ledge: they self-centre, they print without an
unsupported horizontal overhang, and because USB-C is reversible they work
whichever face the PCB tail is flush with — a dimension not measured and not
needed.

**Insertion direction: from the BACK FACE, tail first — and soldered after
seating.** This follows directly from the numbers above and is not optional.
The ramps narrow the collar bore to **1.82 mm** from z 3.38 up, while the
jack's metal shell is **3.17 mm** thick: only the thin PCB tail can pass that
channel. So the tail goes up through the slot and out of the channel, the
metal shell follows into the full 3.42 mm slot and wedges on the ramps, and
the mouth ends flush with the back face. Seating it "from inside, mouth
first" is physically impossible — it would lever a 3.17 mm metal part through
a 1.82 mm gap between two 1.5 mm PETG walls.

Because the tail's pads land at z = 6.42, above the 4.5 mm collar, the wires
are soldered **after** the jack is seated (see Deliverables). Order: seat →
test-fit a cable → solder → epoxy.

**Pull-out retention is adhesive.** Two dabs of epoxy in the collar. There is no
printed alternative: the part presents no rearward-facing surface to catch. The
load is the plug's own latch force on unplug (order 10 N) spread over ~40 mm² of
glued wall, so this is adequate, not marginal — but it is glue, and the README
must say so.

**Clearances:** 1.09 mm from the collar to the +X plate edge, 0.64 mm to the
-Y edge, 2.09 mm of solid plate between the slot and the nearest rear LEGO
counterbore. The ±X snap pockets (y ±12) are untouched — they are on the X
edges only, so both Y bands are free.

### 2. Capacitor cradle (`02_backplate.py`, new step)

Laid on its side in the **+Y band**, which is otherwise empty. Standing it was
rejected: 12 mm in a 14 mm cavity, leads pointing at the lid, and a footprint
that only fits the -Y band by ~0.1 mm alongside the jack.

- Two C-clip saddle ribs, **1.2 mm** thick, inner radius 4.3 (= `capDia/2` +
  `capClear/2`), outer radius 5.5, at **x 5.0 and x 14.8** (9.8 mm apart).
- Cap axis at **y +16.75, z 5.5**; body occupies x 3.9…15.9, y 12.65…20.85,
  z 1.4…9.6. Ribs span y 11.25…22.25 — 0.6 mm clear of both the XIAO fence
  and the plate edge.
- Top opening 7.0 mm so the cap snaps down past the equator (0.6 mm deflection
  per arm). No lid boss required.
- **Rib positions are set by the LEGO Technic bores, not by the clip
  trenches** *(corrected 2026-09-09, final review; the ribs were at x 3.0 and
  12.8)*. The ribs run y 11.25…22.25 at z 0…8, which crosses the y band of the
  bores at (0.95, ±12) — radius 2.45, so x -1.50…3.40, y 9.55…14.45. The old
  x = 3.0 rib (footprint x 2.40…3.60) overlapped that bore by **1.00 mm in x
  over 3.20 mm in y**, roofing ~11 % of its interior mouth for the rib's full
  8 mm height: a Technic pin pushed in from the back would have bottomed out
  on the rib, silently costing one of the six mount holes. At x 5.0 the rib's
  left edge is x 4.40, a full 1.00 mm clear of the bore edge at 3.40.
- ~~The -X rib now overlaps the outboard +Y clip trench **in plan** (rib
  x 4.40…5.60 vs trench x 4.4…11.6, over y 11.25…11.85). This is harmless
  and must not be "fixed": the rib is z 0…8.0 and the trench z -1.5…0, so
  they never share space.~~ *(Moot 2026-09-10: the clip trenches are deleted,
  so the floor under the rib is plain solid plate and the two features no
  longer meet even in plan. The probe at (5.0, 11.5, -0.75) that guarded this
  was removed with them.)* Rib placement is still pinned by the Technic bores
  above, and `90_verify.check_lego_bores_clear` still guards that.
- Lead end faces **+X**.

### 3. Wire routing

- **Jack to XIAO:** ~10 mm within the -Y band. A **3.5 mm wide x 2.5 mm deep
  notch** is cut in the -Y fence wall at **x 14.5…18.0**, directly outboard of
  the 5V/GND pads, so the pair drops straight down instead of being pinched
  between the board edge and the wall. Clear of the XIAO clip at x 4.5…11.5.
  The same notch is cut in the **+Y** wall for symmetry and as insurance
  against the pads being on that edge.
- **Capacitor to the 5V rail:** over a fence bar, or through a wire notch.
  *(Corrected 2026-09-09, final review — the original text here claimed "the
  XIAO fence is open on +X, giving a full-height channel at x 19.3…20.85".
  There is no such channel. The ±Y fence bars are drawn 26.0 mm wide centred
  on x 8.0, i.e. x -5…21, and are trimmed only by the plate outline at
  x 20.85, so they run the full width. It is the **board** that ends at
  x 19.23, not the wall. Probed on the built plate: solid at y ±9.9,
  z 0.5/2.0/4.0/4.9 continuously from x 18.25 to x 20.75, void at x 21.0.)*
  The cap's leads run +X and then reach the -Y band either **over the top of
  a fence bar** — the bars stop at z = 5.0 in a 14 mm cavity, so there is
  about 9 mm of headroom (probed void at z 5.2) — or **through the ±Y wire
  notches and across the bay above the XIAO**. No new feature needed either
  way.
- The junction may be made at the jack pads or at the XIAO pads; the case
  supports either.

### 4. Shell USB notch deleted (`03_shell.py`)

Remove step 4 (the notch cut through the +X wall) and step 6d (the notch
edge-softening pass). The step-6 edge-count guard expects the notch to split the
+X segment at `z_back` into 9 edges; that becomes **8**. `usbClear` joins
`tapeRecess` as a dead user parameter — both are left in place rather than
re-running `01_setup.py`, which resets user-tuned values.

Consequence, to be recorded in the README: **the XIAO's USB-C is no longer
reachable with the case closed.** Serial console and USB reflash require
unclipping the lid. OTA remains the normal update path.

### 5. Interior LEGO counterbores deleted (`02_backplate.py`, step 7)

The 6.4 x 0.9 counterbores on the **front (interior)** face are removed; the
rear ones are unchanged. A Technic pin is only ever inserted from the back, so
the interior counterbores serve nothing and their recesses fall where printed
features want flat floor. Result: one flat interior floor.

### 6. XIAO clips — 1.5 mm fingers on a longer lever (`02_backplate.py`, 8b)

> **SUPERSEDED 2026-09-10 — the slots and trenches described in this section
> no longer exist.** The user printed this design, handled it, and reported
> the XIAO clips as *"very wimpy — barely holding it in"*, then instructed
> that the slots and the trenches be removed. They were: `02_backplate.py`
> step 8b now passes `NO_SLOTS`, and step 8c (the four clip-root trenches)
> is deleted outright. Each XIAO clip is now a 7 mm stretch (x 4.5…11.5) of
> the **continuous** 1.5 mm fence wall, raised locally to 5.6 mm, carrying
> the same 0.60 mm lip with its flat underside at z 4.30 for 0.34 mm of
> grab per side. Lip, grab and float are unchanged — a lip change was
> offered and declined.
>
> **What this section got wrong, and it is worth keeping to see it.** The
> analysis below is internally correct: on an isolated end-loaded
> cantilever, a 1.5 mm finger at 0.34 mm of grab really does want a longer
> lever, and the trenches really did take peak strain from 4.1 % to 2.3 %.
> But strain was never the constraint that mattered on this part. The
> design minimised a failure (a cracked finger) that had not occurred,
> at the direct expense of the function (holding the board) that had. The
> before/after table below is a table of the wrong figure of merit.
>
> No strain or force number is quoted for the replacement, deliberately. A
> wall anchored along its whole base and continuous with its neighbours out
> to the plate edge, loaded near its top, is not a simple cantilever;
> reusing the 3·t·d/(2·L²) formula on it would produce a confident number
> that means nothing. Qualitatively: substantially stiffer, so
> substantially more retention, **and the trade is insertion force** —
> firmer to seat, and a fingernail or spudger to release.
>
> Knock-on effects: `X_TRENCH_Z0` and `X_SLOT_Z0` are deleted as dead;
> the slot-to-bore web hazard described at the end of this section is moot
> (no slot, no web) though its *lesson* is not; and the plate volume rose
> 16.741 → 16.821 cm³, matching the 79.86 mm³ of restored material
> (51.84 mm³ of trench + 28.02 mm³ of slot) to within rounding.
> `90_verify.check_xiao_clips` was retargeted at the new geometry, and now
> also probes **above** the floor (x 4.1 / 11.85, y ±9.9, z 2.0) so a wall
> still sliced through at full height cannot pass.

The finger goes to **1.5 mm**, the fence wall's own thickness, so the `thin=`
shave disappears. A 1.0 mm wall is not reliably printable on the user's 0.6 mm
nozzle.

At the current 4.30 mm lever a 1.5 mm finger at 0.34 mm grab reaches **4.1%**
strain, which is at PETG's yield. The fix is a longer lever, **not** a smaller
lip: at 0.6 mm the nozzle resolves 0.6 and 1.2 cleanly, so a reduced 0.51 mm lip
would print worse than the 0.60 mm already there.

- **Trenches:** 1.2 mm wide x 1.5 mm deep, one either side of each finger,
  spanning x 4.4…11.6 (0.1 mm into each slot, so no coincident faces) —
  inboard at y ±7.95…±9.15, outboard at y ±10.65…±11.85, z -1.5…0.
- **Slots:** the two end slots extend down from the finger top to **z = -1.5**
  (was 0.0), so the blade below the floor is free on all four sides and rooted
  only at z = -1.5. They are **0.7 mm wide — x 3.8…4.5 and 11.5…12.2**
  *(narrowed from 1.0 mm on 2026-09-09, final review)*. Taking the slots below
  the floor put them into the plate BODY for the first time, and at 1.0 mm the
  inboard slot's corner (3.5, ±10.66) sat 2.881 mm from the bore centre at
  (0.95, ±12) — only **0.431 mm** of PETG to the 2.45 mm bore wall, below what
  a 0.6 mm nozzle resolves, so the slicer drops or merges it. At 3.8 the
  corner is 3.149 mm out and the web is **0.700 mm**, one clean extrusion.
  Nothing about the spring changes: the finger is still x 4.5…11.5, so lever,
  strain and grab are untouched; a 0.7 mm gap still clears the finger's
  0.34 mm deflection with 0.36 mm to spare; and the trenches still overlap
  both slots (4.4…4.5 and 11.5…11.6), so the blade stays free at its ends.
- **Lip and grab unchanged:** 0.60 mm projection, 0.34 mm grab per side.

| | before | after |
|---|---|---|
| finger thickness | 1.0 mm | 1.5 mm |
| lever | 4.30 mm | 5.80 mm |
| lip / grab | 0.60 / 0.34 mm | unchanged |
| peak strain | 2.8% | 2.3% |
| retention force | 1x | 1.4x |

The cantilever model is conservative: the blade is also restrained along its
root line, so real strain is slightly lower and force slightly higher.

Trench placement is checked clear of the snap pockets (±X edges, z -1.7…-0.3)
and of every LEGO hole — the x 8.95 column carries holes only at y ±4, and the
x 0.95 column reaches only x 3.40, outside the trenches' x 4.4…11.6.

**That check was necessary but not sufficient, and the gap cost a defect.**
Taking `X_SLOT_Z0` below the floor moved the **slots** into the plate body as
well as the trenches, and the slots sit *outboard* of the trenches in x — at
x 3.5…4.5 the inboard slot came within 0.431 mm of the (0.95, ±12) bore. Any
future change that pushes a clip feature below z = 0 must be checked against
the bores itself, not by inheriting the trenches' clearance. This is now
mechanised: `90_verify.check_lego_bores_clear` probes all six bores plus the
slot-to-bore web directly.

## New Fusion user parameters

Added by `02_backplate.py` itself via `des.userParameters.add`, **not** by
`01_setup.py`, which must not be run or edited.

| name | value | meaning |
|---|---|---|
| `usbJackW` | 9.08 mm | jack widest section (PCB) |
| `usbJackT` | 3.17 mm | jack thickness |
| `usbJackL` | 14.42 mm | jack overall length |
| `usbShellL` | 10.58 mm | metal shell length; sets the ramp height |
| `usbJackClear` | 0.25 mm | total slot clearance (0.125/side) |
| `capDia` | 8.2 mm | capacitor diameter |
| `capLen` | 12.0 mm | capacitor body length |
| `capClear` | 0.4 mm | total cradle clearance |

## Printability

User prints **PETG on a 0.6 mm nozzle**. Every new wall is 1.2 or 1.5 mm — two
clean extrusions or two at 0.75. The seating ramps *add* material (1.5 to
2.3 mm) rather than thinning anything. Slot and fence notches are voids, where
1.2 mm is comfortable. The only sub-1.2 mm feature in the design is the
**0.60 mm clip lip**, which is exactly one extrusion and is deliberate.
*(2026-09-10: the clip trenches referred to here are deleted -- see the
superseded note in section 6.)*

## Verification

Scripted, before anything is printed:

1. **Interference:** a proxy solid of the jack (14.42 x 9.08 x 3.17 with the
   shell/tail step) positioned mouth-flush, and a 8.2 x 12.0 cylinder at the cap
   axis, each intersected with the plate and with the shell — all must give
   zero volume.
2. **Probe:** measure and assert slot cross-section, ramp start z = 2.58, collar
   outer extents and lip projection 0.60. *(2026-09-10: the trench-depth and
   slot-z0 assertions are gone with the features -- `90_verify` now asserts
   solid plate at those points instead, and asserts the fence wall continuous
   above the floor at the old slot bands.)*
2b. **LEGO bore clearance** (added 2026-09-09, final review): for each of the
   six bore centres, assert void at the centre *and* at ±1.5 mm in x, all at
   z = 0.5 — half a millimetre above the interior floor, where every
   floor-borne feature would show. The off-centre pair is the part that
   bites: the offending cradle rib straddled only the bore's +x flank, so a
   centre-only probe would have passed. *(The extra `solid` at
   (3.3, ±10.5, -0.75) for the slot-to-bore web was removed on 2026-09-10:
   with no slot there is no web, so it had become trivially true. The six-bore
   sweep itself is untouched.)*
3. **Body counts** after every join/cut, with explicit `participantBodies` on
   every boolean (the all-body-participation trap that consumed the BackPlate
   once already).
4. **Shell:** exactly one body; the +X wall is continuous, 8 edges at `z_back`.
5. **Export** both STLs; report bounding boxes and triangle counts, and confirm
   the shell's bbox lost the notch.

Physical acceptance is the user's: print, seat the jack, check the plug bottoms
out and the ramps stop it; snap the cap in; clip the XIAO in and confirm the
1.5 mm fingers still snap by hand.

## Deliverables

- `case/fusion_scripts/02_backplate.py` — jack slot + collar + ramps, cap
  cradle, ±Y fence notches, interior counterbores deleted, XIAO clip rework.
- `case/fusion_scripts/03_shell.py` — USB notch and its edge-softening removed,
  edge-count guard corrected.
- `case/rd03d_case_back.stl`, `case/rd03d_case_shell.stl` — re-exported.
- `case/README.md` — jack assembly order (**seat from the back face tail
  first, test-fit a cable, THEN solder the tail pads, then epoxy** — corrected
  2026-09-09 from the impossible "solder tail first, seat from inside"; see
  the insertion-direction note under Geometry §1), the 5.1 kOhm CC pulldown
  reminder, cap orientation, wire routes, and the note that closing the case
  now blocks the XIAO's USB-C.

## Risks and assumptions

- **Plug overmold size is assumed 12.4 x 6.8 mm.** The binding dimension is
  the overmold's **thickness** (6.8 in that assumption) — the short axis,
  which runs along **Y**, across the slot's short axis. The slot is centred at
  y -19.0 and the shell's skirt presents an inner rim face at **y = -23.0** at
  z = -8 (probed), so a symmetric overmold thicker than about **8.0 mm**
  cannot reach the mouth. The overmold's **width** runs along the slot's long
  axis (X) and is unconstrained. Measure the plug across its thin dimension;
  if it exceeds ~8 mm, use a slim or right-angle plug.
  *(Corrected 2026-09-09, final review. This risk previously read "an overmold
  14 mm or wider will foul a ball joint in the LEGO hole at (8.95, -12)".
  **There is no hole at (8.95, -12).** The x 8.95 column carries holes only at
  y ±4; the six built centres are (0.95, ±12), (0.95, ±4), (8.95, ±4). The
  named obstruction did not exist, and the dimension named — width — was the
  unconstrained one.)*
- **PCB tail thickness was not measured.** The 1.82 mm channel above the ramps
  accepts anything from 0.8 to 1.8 mm, so it does not need to be.
- **Pull-out retention is glue**, by necessity, not choice.
- Fusion API length unit is **cm**; the scripts use the existing `MM = 0.1`
  convention.

## Out of scope

- The 5.1 kOhm CC1/CC2 pulldowns — the user is fitting these to the jack's pads.
- Any change to `01_setup.py`, or renaming `xiaoW`/`xiaoH`.
- The deferred slim in-line case variant.
- Firmware changes; a second sensor node.

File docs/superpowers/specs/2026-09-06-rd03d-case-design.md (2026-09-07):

# RD-03D + XIAO Case — Design

**Date:** 2026-09-06
**Deliverable:** 3D-printable two-part case, built as a NATIVE Fusion 360
parametric design directly in the user's running Fusion instance via its MCP
server (http://127.0.0.1:27182/mcp — Autodesk adapter, `script` feature runs
Python against the live Fusion API). Revised 2026-09-07 from the earlier
CadQuery/STEP-import approach at the user's request: this yields a real
feature timeline and Fusion **user parameters**, fully editable in Fusion.
**Boards (from the user's STEP models, measured with the OCC kernel):**
- RD-03D radar stick: 15.10 × 44.02 mm, 6.35 mm thick incl. rear connector
  (`/Users/me/Downloads/rd-03d-sensor-1/RD-03D.step`)
- XIAO ESP32-C6: 22.46 × 17.78 mm footprint (incl. USB-C overhang), 4.46 mm
  tall (`/Users/me/Downloads/seeed-studio-xiao-esp32-c6-1/Seeed
  Studio XIAO ESP32-C6.step`)

## Decisions Made

- **Mounting (revised 2026-09-07 change request):** LEGO Technic interface —
  the back plate is 8 mm thick (`backT`) with SIX ⌀4.9 mm through-holes on
  the exact 8 mm LEGO pitch (a 1×4 column at x=0.95 plus a 1×2 column at
  x=8.95, rows y=±4 / ±12), counterbored 6.4×0.9 both faces with chamfered
  entries, so standard pins/ball-pins/socket arms mount the case with
  adjustable aim. The flat back + 0.6 mm tape recess remain as a secondary
  adhesive option. Case deepens to 46×50×24 overall.
- **Assembly:** snap-fit — front shell with four cantilever clips engaging the
  back plate rim. Tool-free open.
- **Format:** native Fusion design. All key dimensions become Fusion USER
  PARAMETERS (wall, window thickness, clearances, snap sizes) so the user
  edits them in Modify → Change Parameters and the model updates. The MCP
  build scripts are committed to the repo for reproducibility; the design
  itself lives in the user's Fusion (they save it to their own project).

## Layout

Two printed parts:

1. **Back plate** — flat, 8 mm thick (Technic-depth; see Mounting), adhesive
   face with a 0.6 mm recessed tape pocket and the six Technic holes.
   Carries the board mounts:
   - RD-03D: edge-rail pocket (board has no mounting holes) holding the stick
     patch-side-forward; small retention nubs; ≥7 mm clearance behind the
     board for its rear connector + jumper wires.
   - XIAO: corner posts registering the board outline, USB-C port aligned to
     the shell's short-side cutout.
   - Boards side by side; open channel between them for the 4 jumper wires.
2. **Front shell** — 2 mm walls, drops over the back plate, four snap clips.
   - **Radar window:** front wall thinned to 1.2 mm in a panel covering the
     RD-03D antenna end. No other feature in front of the patches.
   - **USB-C cutout:** a notch through the shell rim on a short side (prints
     support-free), sized for a typical USB-C plug overmold (~10.5 × 6 mm
     opening + 0.4 mm clearance).

Interior target ≈ 48 × 40 × 14 mm; exact numbers derive from the parameter
block (board dims + clearances), not hardcoded magic values.

## Parameters (Fusion user parameters)

`wall`, `windowT`, `boardClear` (0.25 mm), `usbClear` (0.4 mm), snap clip
dimensions/engagement (FDM-tolerant), `tapeRecess`, fillet radii — created
via the API as named user parameters with expressions, editable in Fusion's
Change Parameters dialog. Sketches/features reference the parameters, not
literal numbers, wherever the API reasonably allows.

## Verification (scripted in Fusion, before anything is printed)

The build imports the user's actual board STEP models into the design
(reference components, positioned) and checks:
1. **No interference:** boolean intersection of each board with each case part
   has (near-)zero volume.
2. **USB alignment:** the XIAO's USB-C connector solid projects through the
   shell cutout with clearance on all sides.
3. **Window coverage:** the thinned panel fully covers the radar patch end
   (top ~20 mm of the stick) with margin.
4. **Assembly sanity:** back plate rim fits inside shell cavity with the
   design gap; combined bounding box reported.
Interference via Fusion's own interference analysis / measure API; visual
verification via the MCP screenshot query (front/back/open views) — and the
user watches the model appear live in their own Fusion window.

## Deliverables

- The design itself: a new Fusion document built live in the user's Fusion
  (components: BackPlate, FrontShell, plus the two imported board models),
  with user parameters. The user saves it to their own hub/project.
- Committed under `case/` in the repo:
  - `case/fusion_scripts/*.py` — the numbered MCP build scripts (rerunnable
    record of how the design was constructed).
  - `case/rd03d_case_back.stl`, `case/rd03d_case_shell.stl` — exported from
    Fusion via the API, print-ready.
  - `case/README.md` — print settings (PLA/PETG, 0.2 mm layers, no supports,
    shell printed opening-up), assembly/wiring note, which user parameters to
    tweak for fit.

## Print Assumptions

FDM, PLA or PETG, 0.4 mm nozzle, 0.2 mm layers, no supports for either part.
Snap clips oriented so layer lines don't peel (clips print vertically as part
of the shell walls).

## Out of Scope

- Keyhole/screw mounting variants, light pipes, button access (device is
  OTA-updated; physical access = unclip the lid).
- CadQuery/OpenSCAD sources (superseded by the native build).
- A second-node case variant (same design reprints as-is).
- Cloud-saving the document for the user (they save into their own project).

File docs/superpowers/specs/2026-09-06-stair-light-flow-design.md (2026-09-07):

# Stair Light Node-RED Flow — Design

**Date:** 2026-09-06
**Runs on:** the user's Node-RED (IOTstack, same host as the MQTT broker `iotstack.local:1883`)
**Consumes:** rd03d MQTT topics (see `2026-09-06-rd03d-mqtt-design.md`)
**Controls:** a Tasmota-style MQTT relay/plug (`cmnd/<device>/POWER` → `ON`/`OFF`)

## Goal

Turn the staircase light on when a radar target is inside a configurable zone,
keep it on while anyone remains active there, and turn it off 60 s after the
last in-zone activity — using only built-in Node-RED nodes, delivered as an
importable flow JSON.

## Decisions Made

- Actuator: Tasmota/relay MQTT on/off. Placeholder command topic
  `cmnd/stairlight/POWER`; the user renames it to their device.
- Trigger: zone rectangle filter on target coordinates (bounds tuned after the
  physical placement test); approach-velocity refinement deferred (one extra
  condition in the filter when wanted).
- Off behavior: retriggerable 60 s hold via the built-in `trigger` node.
  `{"gone":true}` events and silence are treated identically (inactivity).
  No time-of-day gating.
- Sensor `rd03d/status` is surfaced for debugging but does NOT drive the
  light (a dead sensor resolves through the normal timeout).

## Flow Structure (built-in nodes only)

```
[mqtt in rd03d/target/+] → [zone filter (function)] → [trigger 60s] → [rbe] → [map payload] → [mqtt out cmnd/stairlight/POWER]
                                     ↓ (debug: in-zone events)
[inject "force ON"] ──────────────────────────────────────────────→ [map payload]
[inject "force OFF"] ─────────────────────────────────────────────→ [map payload]
[mqtt in rd03d/status] → [debug: sensor availability]
```

- **Zone filter** (function node, ~15 lines): config constants at the top —
  `ZONE = { xMin: -1500, xMax: 1500, yMin: 300, yMax: 3000 }` (placeholder;
  units mm, matching the radar payloads). Parses the JSON payload; drops
  `gone` events and anything outside the rectangle; forwards in-zone messages
  unchanged. Malformed payloads are dropped silently.
- **Trigger node**: on any incoming message send `ON`; after 60 s of quiet
  send `OFF`; each new message extends the delay. This is the entire on/off
  logic — one ON per occupancy episode, one OFF, self-healing.
- **rbe node** (report-by-exception): forwards only payload *changes*,
  guaranteeing the Tasmota topic never sees repeats.
- **Map payload** (change node): passes `ON`/`OFF` through as the message
  payload for the command topic (Tasmota accepts `ON`/`OFF` strings).
- **Inject buttons**: manual `ON` / `OFF` for testing the light path without
  motion; wired after the trigger logic (via the map node) so they don't
  disturb the timer state.
- **MQTT broker config node**: `iotstack.local:1883`, anonymous — reused for
  all three MQTT nodes.

## Multi-Target Semantics

All three `rd03d/target/+` topics feed the same filter; any in-zone target
extends the hold. The light goes off 60 s after the *last* in-zone activity,
regardless of which tracking slot produced it (slot numbers are not stable
identities and are deliberately ignored).

## Edge Behavior

- Broker or Node-RED restart: state re-derives from the next occupancy
  event. One known wart: a Deploy/restart during an active hold loses the
  timer, so a lit light stays lit until the next occupancy episode ends —
  documented in the README rather than special-cased in the flow.
- Radar reboot (e.g. OTA): reconnect republish may re-light the stairs if
  someone is in zone — correct.
- Sensor offline while light is on: trigger's 60 s expiry turns it off.
- Two people: last one to leave starts the countdown.

## Deliverables

- `node-red/flows-stair-light.json` — importable flow (Menu → Import).
- `node-red/README.md` — import steps; the three edit points (broker config
  if theirs differs, Tasmota device topic, zone bounds); tuning procedure:
  walk the stairs watching the flow's debug output alongside the radar chart
  (`http://rd03d.local`), read your x/y from the chart HUD at the approach
  positions, set the rectangle, redeploy.

## Testing / Verification

1. Static: flow JSON imports cleanly into Node-RED (validated structurally
   before delivery; final import is on the user's instance).
2. From this Mac (no Node-RED needed): a python paho-mqtt harness plays the
   roles — subscribe to `cmnd/stairlight/POWER` while publishing synthetic
   `rd03d/target/1` messages (in-zone, out-of-zone, gone) — BUT this only
   works once the flow runs in the user's Node-RED; until then the harness
   serves as the acceptance script the user runs after import.
3. Real test: user walks the stairs; light on within a beat, off ~60 s after.

## Out of Scope

- Approach-direction filtering (noted one-liner for later).
- Dimming/effects (relay is on/off), multi-zone, second sensor node,
  time-of-day gating.
- Installing/configuring Node-RED or Tasmota themselves.

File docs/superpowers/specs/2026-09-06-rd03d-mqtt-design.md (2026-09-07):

# RD-03D MQTT Publishing — Design

**Date:** 2026-09-06
**Target:** Seeed Studio XIAO ESP32-C6 (existing `rd03d_uart/` project)
**Framework:** ESP-IDF v5.5 (`~/esp/esp-idf-v5.5`), built-in `mqtt` (esp-mqtt) component
**Builds on:** WiFi/web UI and OTA designs (both done, merged, hardware-verified)
**Consumer:** Node-RED on the user's IOTstack (broker `iotstack.local:1883`, anonymous)

## Goal

The XIAO publishes radar detections over MQTT so LAN automations (Node-RED) can
react — but only when a target has actually moved a preset distance, so topics
carry events, not an 11 Hz firehose.

## Decisions Made

- Broker: `iotstack.local`, port 1883, **anonymous** (no credentials).
- **Per-target topics**: `rd03d/target/1` … `rd03d/target/3`.
- Movement payload: `{"x":-551,"y":550,"v":0}` (mm, mm, cm/s — same units as
  the WebSocket JSON).
- **Gone events**: when a previously-published target stops being reported,
  publish `{"gone":true}` once to its topic.
- Threshold: Euclidean distance vs the **last published** position, default
  **200 mm**, configurable via menuconfig.
- Availability: MQTT Last-Will on `rd03d/status` — retained `online` on
  connect; broker publishes retained `offline` when the device drops.
- QoS 0 everywhere; retain only on `rd03d/status`.
- Delivery of this feature to the device happens **via OTA** (no USB).

## Configuration (Kconfig, non-secret — defaults committed)

Added to the existing `RD03D Configuration` menu:

| Option | Default | Meaning |
| --- | --- | --- |
| `RD03D_MQTT_HOST` | `iotstack.local` | Broker hostname (`.local` resolved via mDNS) |
| `RD03D_MQTT_PORT` | `1883` | Broker TCP port |
| `RD03D_MQTT_MOVE_MM` | `200` | Minimum movement (mm) between publishes per target |

## New Module: `main/mqtt_pub.c/.h`

- `void mqtt_pub_start(void);` — spawns a connect task:
  1. Wait until `wifi_link_has_ip()`.
  2. Resolve the broker: if the host ends in `.local`, query it via
     `mdns_query_a()` (the firmware's mDNS stack is already running — esp-mqtt's
     own resolver uses plain DNS, which cannot see mDNS names); otherwise use
     the hostname as-is. On resolution failure, retry with a 30 s backoff
     (broker may be down/booting).
  3. Start `esp_mqtt_client` against `mqtt://<resolved>:<port>` with the
     Last-Will configured (`rd03d/status` → `offline`, retained). Publish
     retained `online` on `MQTT_EVENT_CONNECTED`. esp-mqtt's auto-reconnect
     handles broker restarts thereafter.
  4. On every `MQTT_EVENT_CONNECTED`, reset all per-target published state, so
     currently-present targets republish immediately — a consumer that
     (re)subscribes never waits indefinitely for state.
- `void mqtt_pub_frame(const rd03d_frame_t *f);` — called from the radar loop
  for every parsed frame:
  - Not connected → return immediately (no queuing, no blocking).
  - Per target i (1-based topic index): if present and (never published since
    connect OR `dx² + dy² ≥ threshold²` vs last published x/y) → publish the
    movement JSON, record the new position. If absent and previously
    published → publish `{"gone":true}` once, clear the state.
  - Publishes use QoS 0 / no retain and must never block the radar loop
    (esp-mqtt enqueues internally; on failure the event is simply dropped —
    the next movement retriggers).

## Wiring (`main/main.c`)

- `mqtt_pub_start();` after `web_server_start()` /
  `ota_update_register(...)`.
- `mqtt_pub_frame(&frame);` in the parse branch next to
  `web_server_send_frame(...)`.
- Everything else — parser, chart, WebSocket, OTA, validation — untouched.
  `main/rd03d.c/.h` untouched.

## Message Flow Examples

- Person walks through the zone: `rd03d/target/1` gets a message roughly every
  200 mm of travel; standing still (even for minutes) produces silence; leaving
  produces one `{"gone":true}`.
- Device power lost: broker publishes retained `offline` on `rd03d/status`.
- Broker restarts: esp-mqtt reconnects, `online` republished, current targets
  republish immediately.

## Error Handling

- Broker unresolvable/down at boot → resolve/connect retry loop (30 s), radar
  loop and all other features unaffected.
- Connection lost mid-run → esp-mqtt auto-reconnect; publishes silently skipped
  meanwhile; state resets on reconnect.
- The `gone` event for a target that disappears while disconnected is lost by
  design (QoS 0, no queue) — the reconnect-republish covers present targets,
  and an absent target's topic simply stops updating. Acceptable for this use.

## Testing / Verification

1. Host parser tests still pass (parser untouched).
2. Deliver via OTA; `/version` shows the new build.
3. Mac-side subscriber (python `paho-mqtt` in the scratchpad venv) on
   `rd03d/#`:
   - `rd03d/status` → `online` (and retained for late subscribers).
   - Walk test: movement messages with sane coordinates, cadence consistent
     with ~200 mm steps; stand-still silence; `{"gone":true}` after leaving.
   - Power-pull test: broker emits retained `offline` (LWT), then `online`
     after reboot.
4. Console log shows resolve → connect → publish lines; radar/chart unaffected.

## Out of Scope

- TLS, authentication (broker is anonymous by decision).
- QoS 1/2, message queuing while offline, retained target topics.
- Node-RED flow itself (consumer side is the user's).
- Home Assistant discovery (user runs Node-RED only).

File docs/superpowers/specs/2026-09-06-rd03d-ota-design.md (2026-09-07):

# RD-03D Firmware OTA Updates — Design

**Date:** 2026-09-06
**Target:** Seeed Studio XIAO ESP32-C6 (existing `rd03d_uart/` project, 4 MB flash — verified via esptool `flash_id`)
**Framework:** ESP-IDF v5.5 (`~/esp/esp-idf-v5.5`)
**Builds on:** `2026-09-06-rd03d-wifi-design.md` (WiFi + web UI, done and verified)

## Goal

Update the wall-mounted XIAO's firmware over WiFi — upload a new `.bin` from a
browser page or one curl command — with automatic rollback so a bad update can
never strand the device: worst case it reboots back into the previous working
firmware.

## Decisions Made

- **Push to device** (no external hosting): the existing esp_http_server gains
  an upload endpoint.
- **Open endpoint** on the trusted home LAN — no token/auth (revisit if the
  network's trust model changes).
- **Rollback enabled** (`CONFIG_BOOTLOADER_APP_ROLLBACK_ENABLE`): a new image
  must prove itself before becoming permanent.

## Partition Layout (one-time USB migration)

Current state: config says 2 MB flash, single 1 MB factory app partition; the
app binary is ~982 KB (≈6% headroom). Actual flash chip is 4 MB.

New custom `rd03d_uart/partitions.csv`:

| Name | Type | SubType  | Size |
| --- | ---- | --- | --- |
| nvs | data | nvs | 24 KB |
| otadata  | data | ota | 8 KB |
| phy_init | data | phy | 4 KB |
| ota_0 | app  | ota_0 | ~1.5 MB  |
| ota_1 | app  | ota_1 | ~1.5 MB  |

`sdkconfig.defaults` gains: 4 MB flash size, custom partition table filename,
rollback enable. Installing the new table requires one final USB
`idf.py erase-flash flash` (nothing persistent is lost: WiFi credentials are
build-time config; NVS holds only RF calibration, which regenerates).

## Firmware Changes (`rd03d_uart/`)

- `main/ota_update.c/.h` — new module, registered on the existing HTTP server:
  - `ota_update_register(httpd_handle_t server)` — adds the two URI handlers.
  - `GET /update` — small self-contained embedded page (C string, not an
    EMBED_FILES asset): shows the running firmware version and slot,
    file picker + upload button, status/progress text, link back to `/`.
  - `POST /update` — streams the request body in chunks via
    `esp_ota_begin` / `esp_ota_write` into the passive slot; on success
    `esp_ota_end` + `esp_ota_set_boot_partition`, respond with a success
    message, then `esp_restart()` after ~1 s (letting the response flush).
    On any failure (image header invalid, oversize, write/verify error):
    respond with the error text and leave everything untouched — the running
    slot is never written, so a failed upload has zero effect.
- `main/web_server.c/.h` — gains `httpd_handle_t web_server_handle(void)`
  (NULL when the server failed to start); `main.c` wires the modules:
  `ota_update_register(web_server_handle())` after `web_server_start()`.
  Chart page HUD additionally shows the firmware version string.
- `main/wifi_link.c/.h` — expose "has an IP" state (simple getter or event
  flag) for the validation logic.
- `main/main.c` — self-validation task/logic: after boot, once WiFi has an IP
  AND the web server started successfully, call
  `esp_ota_mark_app_valid_cancel_rollback()`. If that state is not reached
  within **90 s** of boot, call `esp_restart()` — with the image still
  pending-verify, the bootloader then reverts to the previous slot. (On a
  USB-flashed image or an already-validated image, the mark call is a no-op /
  skipped; the 90 s restart applies only while the image is pending-verify.)
- **Version visibility:** app version comes from git (`git describe --always
  --dirty` via CMake) into `esp_app_desc`; printed in the boot log, shown on
  the chart HUD and the `/update` page, so every update is visibly confirmed.
- `main/rd03d.c/.h` — untouched. Radar loop and chart streaming keep running
  during an upload (flash writes briefly stall tasks; the UART ring buffer
  absorbs it and the parser resyncs if a byte is ever lost).

## Update Flow (user's view)

1. `idf.py build` on the Mac.
2. Browser: open `http://rd03d.local/update`, pick
   `rd03d_uart/build/rd03d_uart.bin`, upload — or:
   `curl -X POST --data-binary @build/rd03d_uart.bin http://rd03d.local/update`
3. Device writes, verifies, reboots into the new slot (~15 s total).
4. New firmware joins WiFi, web server comes up → marks itself valid.
5. Chart page reconnects on its own; HUD shows the new version.

If step 4 never completes: the device restarts after 90 s and the bootloader
boots the previous firmware, which marks itself valid again. No ladder.

## Error Handling

- Upload of a non-firmware file / truncated file → `esp_ota_end` verification
  fails → error response, no state change.
- Upload larger than the slot → rejected mid-stream with an error response.
- Power loss during upload → old slot still boots (passive slot was the only
  thing being written).
- Crash loop in new firmware → watchdog/panic reboot while pending-verify →
  bootloader rollback.
- Concurrent uploads → second POST rejected while one is in progress.

## Testing / Verification

1. Host parser tests still pass (regression; parser untouched).
2. One-time USB migration: erase-flash + flash; radar frames, chart, mDNS all
   still work; boot log shows `ota_0` as the running partition and the new
   version string.
3. Happy-path OTA: bump the version (any commit), build, upload via curl;
   device reboots; HUD/boot log show the new version and the other slot.
4. Browser-path OTA: same via the `/update` page.
5. Rollback drill: build with a temporary test flag that skips validation and
   restarts (simulating a broken image); upload it; confirm the device comes
   back by itself on the previous version within ~2 minutes.
6. Bad-file drill: upload a text file; expect an error response and an
   unaffected running system.

## Out of Scope

- Authentication/signed images (open LAN endpoint by decision above; IDF's
  image hash check still rejects corrupt/non-firmware uploads).
- Pull-based updates, update servers, fleet management.
- OTA of the bootloader or partition table (not possible via esp_ota; USB
  only).

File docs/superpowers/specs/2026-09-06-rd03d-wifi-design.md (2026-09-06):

# RD-03D WiFi Streaming — Design

**Date:** 2026-09-06 (revised same day: browser UI served from the XIAO replaces
the Processing network mode — user pivot after Task 2 landed)
**Target:** Seeed Studio XIAO ESP32-C6 (existing `rd03d_uart/` project)
**Framework:** ESP-IDF v5.5 (`~/esp/esp-idf-v5.5`)
**Builds on:** `2026-08-31-rd03d-uart-design.md` (UART reader, done and hardware-verified)

## Goal

Run the XIAO untethered (USB power only) at the radar's intended mounting
location and view live radar targets from any browser on the home network —
Mac or phone — at `http://rd03d.local`, with no Processing sketch and no
installed software.

## Architecture

- **WiFi:** station on the home 2.4 GHz network; credentials via menuconfig
  (`CONFIG_RD03D_WIFI_SSID`/`_PASSWORD`), stored only in the untracked
  `sdkconfig`. Auto-reconnect on drop. *(Implemented — Task 2.)*
- **Radar config:** firmware sends the multi-target command at boot and flushes
  the ACK; viewers never send radar commands. *(Implemented — Task 1.)*
- **Discovery:** mDNS hostname **`rd03d.local`**.
- **UI transport:** ESP-IDF `esp_http_server` with WebSocket support
  (`CONFIG_HTTPD_WS_SUPPORT=y`):
  - `GET /` → a single self-contained embedded HTML page (baked into the
    firmware image via CMake `EMBED_FILES`; no filesystem, no external assets).
  - `GET /ws` → WebSocket pushing one JSON text message per parsed radar frame
    (~10/s).
- **Payload (parsed JSON, not raw bytes):** the firmware reuses the tested
  `rd03d` parser and sends decoded targets:

  ```json
  {"t":[{"x":-551,"y":550,"v":0},null,null],"dropped":0,"bad":0}
  ```

  `t` always has 3 entries; absent targets are `null`. `x`/`y` in mm, `v` in
  cm/s; `dropped`/`bad` are the parser's cumulative link counters.

## Firmware Changes (`rd03d_uart/`)

- `main/wifi_link.c/.h` — as implemented, plus two hardening amendments from
  code review: WPA2 auth-mode threshold (refuse open-network SSID spoofs) and
  compile-time asserts on credential lengths. mDNS init (hostname `rd03d`)
  added here after WiFi start, via the `espressif/mdns` managed component.
- `main/web_server.c/.h` — new module:
  - `web_server_start(void)` — starts `esp_http_server`, registers `/` and
    `/ws` handlers.
  - `web_server_send_frame(const rd03d_frame_t *f, uint32_t dropped, uint32_t bad)`
    — formats the JSON message and sends it asynchronously to every connected
    WebSocket client. Bounded work: a client whose send fails or backs up is
    closed; the radar loop is never blocked. No client connected → no-op.
  - A small number of simultaneous clients supported (HTTP server default
    socket limit; at least Mac + phone together).
- `main/index.html` — the embedded page (see UI section), registered via
  `EMBED_FILES` in `main/CMakeLists.txt`.
- `main/main.c` — after each parsed frame: `print_frame` (unchanged) and
  `web_server_send_frame(...)`. `web_server_start()` called after
  `wifi_link_start()`.
- `sdkconfig.defaults` gains `CONFIG_HTTPD_WS_SUPPORT=y`.
- `main/rd03d.c/.h` — **untouched.**
- USB console output unchanged (free diagnostics when attached).

## Web UI (embedded `index.html`)

Single dark-theme page, no external resources, mobile-friendly viewport:

- Canvas XY chart echoing the Processing sketch: radar at bottom-center
  origin, +Y forward (up), grid with range rings/labels, fixed plot range
  (default ±3 m X, 8 m Y — sensor max range).
- One color per target (T1/T2/T3), current position dot plus a fading trail
  (recent history kept client-side).
- HUD: connection state, per-target `x / y / v` readout, frames-received
  counter, and the firmware's `dropped`/`bad` link counters.
- WebSocket auto-reconnects every ~2 s when closed (XIAO reboot, WiFi blip)
  without freezing the page.

## Processing Sketch

Untouched. It continues to work in its original direct-USB serial mode; the
web page replaces its role for WiFi viewing.

## Error Handling

- WiFi down → firmware reconnect loop; radar reading and console continue.
- No WS clients → sends are no-ops.
- Slow/stalled WS client → that client is dropped; others unaffected.
- Browser side: on WS close, HUD shows "disconnected — retrying" and the page
  keeps retrying.

## Data Rate Sanity

~10 frames/s × ~120-byte JSON ≈ 1.2 KB/s per client — negligible.

## Testing / Verification

1. Host parser tests still pass (parser untouched).
2. `ping rd03d.local` resolves (mDNS).
3. `curl -s http://rd03d.local/ | head` returns the page HTML.
4. Browser on the Mac: live dots track motion; kill/restore XIAO power →
   page shows disconnected, then recovers.
5. Phone browser: same page works simultaneously with the Mac.
6. Untethered: XIAO on a USB power bank at the mounting spot.

## Out of Scope

- Raw TCP byte stream (dropped in the revision; the Processing sketch keeps
  its USB serial mode instead).
- Radar commands from the browser; authentication/TLS; OTA updates; HTTPS.
- WiFi provisioning UI (credentials remain build-time menuconfig).

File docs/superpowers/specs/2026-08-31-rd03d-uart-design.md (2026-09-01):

# RD-03D UART Reader — Design

**Date:** 2026-08-31
**Target:** Seeed Studio XIAO ESP32-C6
**Framework:** ESP-IDF v5.5 (`~/esp/esp-idf-v5.5`; the v5.3.5 install referenced by .vscode/settings.json no longer exists on this machine)

## Goal

First step of a new radar project: the XIAO ESP32-C6 reads binary frames from an
Ai-Thinker RD-03D 24GHz mmWave radar over UART, decodes them, and prints
human-readable target data to the USB-C serial console.

## Hardware / Wiring

| RD-03D pin | XIAO ESP32-C6 pin | Notes |
| --- | --- | --- |
| TX | D7 (GPIO17) | UART1 RX on the XIAO |
| RX | D6 (GPIO16) | UART1 TX; unused for now, wired for future mode commands |
| 5V | 5V | RD-03D is 5V powered (3.3V logic on UART) |
| GND | GND | |

- Radar UART: **256000 baud, 8N1**, no flow control.
- Console: built-in **USB-Serial-JTAG** on the USB-C port — no GPIOs consumed;
  monitor baud rate setting is irrelevant to the radar link.

## Project Structure

New ESP-IDF project `rd03d_uart/` alongside `blink/` and `hello_world/`:

```
rd03d_uart/
  CMakeLists.txt
  sdkconfig.defaults          # target esp32c6, console on USB-Serial-JTAG
  main/
    CMakeLists.txt
    main.c                    # UART1 setup + read task + logging
    rd03d.c                   # frame parser (pure C, no IDF dependencies)
    rd03d.h                   # rd03d_frame_t, rd03d_target_t, parser API
  README.md
```

## Frame Format (from RD03D_RadarChart README / user manual)

30-byte frame: header `AA FF 03 00`, three 8-byte target blocks, tail `55 CC`.

Each target block:

| Offset | Field | Encoding |
| --- | --- | --- |
| 0–1 | X (mm) | 16-bit sign-magnitude, little-endian; MSB of high byte = sign |
| 2–3 | Y (mm) | same sign-magnitude encoding |
| 4–5 | Velocity (cm/s) | same sign-magnitude encoding |
| 6–7 | Resolution (mm) | plain 16-bit little-endian |

An all-zero block means no target in that slot.

## Data Flow

1. `uart_read_bytes()` in a single FreeRTOS task (Approach A: simple polling
   loop; no UART event queue).
2. Bytes are fed one at a time into a parser state machine that hunts for the
   header, accumulates 30 bytes, and validates the tail.
3. On a valid frame the parser fills `rd03d_frame_t` (up to 3 targets, each with
   a `present` flag and decoded x/y/velocity/resolution).
4. `main.c` prints one line per frame, e.g.
   `T1: x=-123mm y=456mm v=-12cm/s | T2: --- | T3: ---`.

## Error Handling

- Garbage or partial frames never crash the parser: any byte that breaks the
  expected sequence resets the state machine, which resynchronizes on the next
  header.
- The parser counts dropped bytes and invalid frames; `main.c` logs these
  counters periodically (~every 5 s) as a link-quality indicator.

## Testing / Verification

- Build and flash with ESP-IDF v5.5 (`source ~/esp/esp-idf-v5.5/export.sh`)
  (`idf.py set-target esp32c6`, `idf.py flash monitor`, port
  `/dev/cu.usbmodem101`).
- Verify parsed target lines appear when a person moves in front of the radar,
  and that the no-target case prints `---` slots.
- The parser is pure C with no IDF dependencies, so it can be unit-tested on
  the host against known capture bytes if needed later.

## Out of Scope (for this step)

- Raw binary pass-through mode for the Processing sketch.
- Sending mode-switch commands to the radar (multi-target mode is the RD-03D
  default).
- Wi-Fi/BLE, storage, or any visualization on the ESP32 side.

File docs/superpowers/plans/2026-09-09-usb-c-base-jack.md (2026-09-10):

# USB-C Base Jack, Capacitor Cradle and Clip Rework — Implementation Plan

> **For agentic workers:** REQUIRED SUB-SKILL: Use superpowers:subagent-driven-development (recommended) or superpowers:executing-plans to implement this plan task-by-task. Steps use checkbox (`- [ ]`) syntax for tracking.

**Goal:** Add a rear-facing USB-C power jack, a 100 uF capacitor cradle and wire routes to the RD-03D case back plate; delete the shell's side USB notch and the interior LEGO counterbores; take the XIAO retention clips to 1.5 mm fingers on a deeper root.

**Architecture:** The case is a live Fusion 360 parametric document (`rd-03d_case`) rebuilt by re-running numbered Python scripts through Fusion's MCP server. `02_backplate.py` deletes and rebuilds the whole `BackPlate` component every run, so "edit the script, re-run it" is the normal edit cycle — there is no incremental state to protect. Verification is a separate read-only script, `90_verify.py`, that probes the rebuilt solids with `BRepBody.pointContainment` and raises on the first bad assertion. Each task adds its assertions to `90_verify.py` **first**, watches them fail, then changes the build script.

**Tech Stack:** Python 3 (stdlib only) driving `http://127.0.0.1:27182/mcp` via `case/fusion_scripts/run_fusion.py`; the Fusion 360 Python API (`adsk.core`, `adsk.fusion`).

---

## Read this before Task 1

These are hard constraints. Violating any of them destroys the user's work or wastes a print.

1. **NEVER run or edit `01_setup.py`.** It rewrites every Fusion user parameter back to its literal default and would discard values the user has tuned by hand. New parameters are added by `02_backplate.py` itself.
2. **NEVER save, close or discard the user's Fusion document.** Do not call `doc.save`, `doc.close` or `app.activeDocument.close`. Saving is the user's step.
3. **Every boolean feature must pass `participantBodies`.** A Fusion Cut/Intersect with no participant list consumes *every* intersecting body in the design — this silently deleted the whole BackPlate once. The `extrude()` helper in `02_backplate.py` takes `participants=[body]`; always supply it.
4. **The Fusion API length unit is centimetres.** Both scripts define `MM = 0.1` and multiply. Every number in this plan is stated in **mm**; write `13.6 * MM` in the code.
5. **If a script fails, Fusion rolls the whole thing back** — you get a clean document, not a half-built one. Re-run after fixing.
6. **A modal dialog open in Fusion blocks mutating scripts.** If a run hangs or reports a stale error, ask the user to check for an open dialog (Change Parameters, etc.) in their Fusion window.
7. The RD-03D parser `rd03d_uart/main/rd03d.c` and its header are out of scope and must not change.

**Running a script:**

```bash
python3 run_fusion.py script 02_backplate.py
```

**Running the verifier (read-only, safe at any time):**

```bash
cd /path/to/rd03d/case/fusion_scripts && python3 run_fusion.py script 90_verify.py --read-only
```

`run_fusion.py` exits non-zero when the script reports failure, so `echo $?` distinguishes pass from fail.

---

## File Structure

| File | Responsibility | Change |
|---|---|---|
| `case/fusion_scripts/90_verify.py` | Read-only geometric assertions over both components | **Create** |
| `case/fusion_scripts/02_backplate.py` | Builds the BackPlate: plate, LEGO holes, bays, fences, clips, and now the jack collar / cap cradle / notches | Modify |
| `case/fusion_scripts/03_shell.py` | Builds the FrontShell: box, cavity, radome step, ribs, boss, edge softening | Modify (delete notch + its softening) |
| `case/fusion_scripts/05_export.py` | STL export of both components | Unchanged, re-run |
| `case/README.md` | Print settings, assembly, wiring | Modify |
| `case/rd03d_case_back.stl`, `case/rd03d_case_shell.stl` | Print-ready meshes | Regenerated |

`01_setup.py`, `00_smoke.py`, `04_boards.py` and `run_fusion.py` are untouched.

---

## Coordinate cheat-sheet (mm)

Referenced constantly below; all confirmed by probe in earlier sessions.

- Plate: x -20.85…20.85, y -22.85…22.85, z -8…0. Interior cavity ceiling z = 14.
- Radar bay: x -19.3…-3.7 between fence walls at x -20.8…-19.3 and x -3.7…-2.2.
- XIAO board: x -3.23…19.23, y ±8.89, PCB top z = 4.20. Bay posts z 0…3.
- XIAO fence walls: y ±9.15…±10.65, z 0…5, spanning x -5…20.85, **open on +X**.
- XIAO clip fingers: x 4.5…11.5 on each ±Y wall; isolating slots x 3.5…4.5 and 11.5…12.5.
- LEGO holes: ⌀4.9 at x 0.95 (y -12, -4, +4, +12) and x 8.95 (y -4, +4); ⌀6.4 × 0.9 counterbores on both faces.
- Snap pockets: **±X plate edges only**, y ±12, z -1.7…-0.3. Both ±Y edges are free.

---

### Task 1: Verification harness

Creates the probe script every later task extends. It must pass against the **current** model before anything changes, which also proves the MCP link works.

**Files:**
- Create: `case/fusion_scripts/90_verify.py`

- [ ] **Step 1: Create the branch**

```bash
cd /path/to/rd03d && git checkout -b feat/case-usb-jack
```

- [ ] **Step 2: Write the harness**

Create `case/fusion_scripts/90_verify.py` with exactly this content:

```python
"""Read-only geometric assertions over the rd-03d_case document.

Run with:  python3 run_fusion.py script 90_verify.py --read-only

Every check is a point-containment probe in MILLIMETRES. `solid(...)` asserts
the point is inside material; `void(...)` asserts it is not. Failures are
collected and raised together so one run reports every problem.
"""
import adsk.core
import adsk.fusion

MM = 0.1
FAILURES = []

def find(root, prefix):
    """The single body of the component whose name starts with `prefix`.

    A rebuilt component keeps a cosmetic "(1)" suffix until the document is
    saved, so match on prefix rather than equality.
    """
    for occ in root.occurrences:
        if occ.component.name.startswith(prefix):
            comp = occ.component
            if comp.bRepBodies.count != 1:
                raise RuntimeError("%s has %d bodies, expected 1"
                                   % (comp.name, comp.bRepBodies.count))
            return comp.bRepBodies.item(0)
    raise RuntimeError("no component starting with " + prefix)

def _inside(body, x, y, z):
    pt = adsk.core.Point3D.create(x * MM, y * MM, z * MM)
    pc = body.pointContainment(pt)
    return pc == adsk.fusion.PointContainment.PointInsidePointContainment

def solid(body, x, y, z, why):
    if not _inside(body, x, y, z):
        FAILURES.append("EXPECTED SOLID at (%.2f, %.2f, %.2f): %s"
                        % (x, y, z, why))

def void(body, x, y, z, why):
    if _inside(body, x, y, z):
        FAILURES.append("EXPECTED VOID at (%.2f, %.2f, %.2f): %s"
                        % (x, y, z, why))

def check_baseline(plate, shell):
    """Geometry that predates this plan and must survive every change."""
    solid(plate, 0, 0, -4, "plate core")
    void(plate, 0.95, -12, -4, "LEGO through-bore at x0.95 y-12")
    solid(plate, -11.5, -12.0, 1.0, "radar bay crossbar A (y -12.8..-11.2)")
    void(plate, -11.5, 0, 1.0, "radar bay is open between the crossbars")
    solid(plate, -20.0, 0, 6.0, "radar clip A wall at x -20.8..-19.3")
    solid(plate, 8.0, -9.9, 2.0, "XIAO -Y fence wall")
    solid(plate, 8.0, 9.9, 2.0, "XIAO +Y fence wall")
    void(plate, 8.0, -9.9, 6.5, "above the XIAO clip top (5.6)")
    solid(shell, 0, 0, 15.0, "shell front wall above the 14 mm ceiling")
    void(shell, 0, 0, 7.0, "shell interior cavity")

def run(_context: str):
    app = adsk.core.Application.get()
    des = adsk.fusion.Design.cast(app.activeProduct)
    root = des.rootComponent
    plate = find(root, "BackPlate")
    shell = find(root, "FrontShell")
    print("plate volume %.3f cm3   shell volume %.3f cm3"
          % (plate.volume, shell.volume))

    check_baseline(plate, shell)

    if FAILURES:
        for f in FAILURES:
            print("FAIL:", f)
        raise RuntimeError("%d verification failure(s)" % len(FAILURES))
    print("VERIFY OK")
```

- [ ] **Step 3: Run it against the current model**

```bash
cd /path/to/rd03d/case/fusion_scripts && python3 run_fusion.py script 90_verify.py --read-only; echo "exit=$?"
```

Expected: prints two volumes then `VERIFY OK`, `exit=0`.

If it reports "no component starting with BackPlate", the user's Fusion has a different document in front; stop and ask them to activate `rd-03d_case`. If a baseline probe fails, do **not** edit the probe to make it pass — report the discrepancy, because it means the live model differs from what this plan assumes.

- [ ] **Step 4: Commit**

```bash
cd /path/to/rd03d && git add case/fusion_scripts/90_verify.py && git commit -m "test(case): read-only geometry verifier for the Fusion model

Point-containment probes over BackPlate and FrontShell, run through the
MCP driver with --read-only. Baseline covers the plate core, a LEGO bore,
the radar clip wall, both XIAO fence walls and the shell cavity.

Co-Authored-By: Claude Opus 5 <noreply@anthropic.com>"
```

---

### Task 2: XIAO clips — 1.5 mm fingers on a 1.5 mm-deeper root

The finger goes to the fence wall's own 1.5 mm thickness (a 1.0 mm wall does not print on the user's 0.6 mm nozzle). To keep peak strain at 2.3% instead of 4.1% the cantilever root drops 1.5 mm into the plate: two trenches either side of each finger, and the existing isolating slots extended down to meet them. Lip (0.60 mm) and grab (0.34 mm) are unchanged — at a 0.6 mm nozzle, 0.60 is exactly one extrusion and a smaller lip would print worse.

**Files:**
- Modify: `case/fusion_scripts/90_verify.py`
- Modify: `case/fusion_scripts/02_backplate.py` (step 8b, near the end of `run()`)

- [ ] **Step 1: Write the failing checks**

In `90_verify.py`, add this function directly above `def run(`:

```python
def check_xiao_clips(plate):
    """1.5 mm fingers, slots and trenches reaching z = -1.5."""
    for sy in (-1, 1):
        tag = "+Y" if sy > 0 else "-Y"
        # trenches: 1.2 mm wide, 1.5 mm deep, either side of the finger
        void(plate, 8.0, sy * 8.55, -0.75, "inboard clip trench " + tag)
        void(plate, 8.0, sy * 11.25, -0.75, "outboard clip trench " + tag)
        # the blade between them survives, and is rooted below the trenches
        solid(plate, 8.0, sy * 9.9, -0.75, "clip blade " + tag)
        solid(plate, 8.0, sy * 9.9, -2.0, "clip blade root below trench " + tag)
        # isolating slots now reach the trench depth
        void(plate, 4.0, sy * 9.9, -0.75, "clip slot runs to -1.5 " + tag)
        void(plate, 12.0, sy * 9.9, -0.75, "clip slot runs to -1.5 " + tag)
        # finger is full 1.5 mm: the old 0.5 mm outer shave is gone
        solid(plate, 8.0, sy * 10.4, 3.0, "finger at full thickness " + tag)
        # lip still projects past the wall's inner face to +/-8.55
        # lip material spans lip_z(4.30)..top_z(5.60); z=4.30 is the board
        # top + 0.10 float, so probe just inside the lip, not in the gap
        solid(plate, 8.0, sy * 8.7, 4.40, "clip lip " + tag)
        # trenches are local to the finger: plate is solid beyond them in x.
        # Probed on the inboard trench's y band - the outboard band at
        # y +/-11.25 passes within 1.29 mm of the LEGO bore at (0.95, +/-12)
        solid(plate, 2.0, sy * 8.55, -0.75, "plate solid beyond trench " + tag)
        solid(plate, 14.0, sy * 8.55, -0.75, "plate solid beyond trench " + tag)
```

Then add the call inside `run()`, immediately after `check_baseline(plate, shell)`:

```python
    check_xiao_clips(plate)
```

- [ ] **Step 2: Run to verify it fails**

```bash
cd /path/to/rd03d/case/fusion_scripts && python3 run_fusion.py script 90_verify.py --read-only; echo "exit=$?"
```

Expected: `exit=1`, with FAIL lines for the trenches, the slot depth and the finger thickness (the lip, blade and "solid beyond trench" checks already pass).

- [ ] **Step 3: Change the clip parameters**

In `02_backplate.py`, in step 8b near the end of `run()`, change these two constants:

```python
    X_SLOT_Z0 = 0.0
    X_RAISE_Z0 = 4.5 * MM                        # inside the 5 mm wall
    X_THIN = 0.5 * MM
```

to:

```python
    # 2026-09-09: finger taken to the wall's own 1.5 mm (a 1.0 mm wall does
    # not print on the user's 0.6 mm nozzle), and the root dropped 1.5 mm
    # into the plate by the trenches below so the lever grows 4.30 -> 5.80
    # mm. Peak strain 3*t*d/(2*L^2) = 3*1.5*0.34/(2*5.8^2) = 2.3%, down from
    # 2.8% at 1.0/4.30 and well clear of the 4.1% a 1.5 mm finger would see
    # on the old lever. Spring rate goes as t^3/L^3 -> 1.4x the old force.
    # The lip stays at 0.60 mm: a 0.6 mm nozzle resolves 0.6 and 1.2, so a
    # smaller lip would print worse, not better.
    X_TRENCH_Z0 = -1.5 * MM
    X_SLOT_Z0 = X_TRENCH_Z0
    X_RAISE_Z0 = 4.5 * MM                        # inside the 5 mm wall
    X_THIN = 0.0
```

- [ ] **Step 4: Add the trench cuts**

In `02_backplate.py`, immediately **after** the `for sy in (-1, 1):` clip loop in step 8b and **before** the final `print("BackPlate bodies:", ...)`, insert:

```python
    # 8c. Clip-root trenches. Free the finger below the plate floor so its
    # cantilever root sits at X_TRENCH_Z0 instead of z=0. Spans x 4.4..11.6
    # (0.1 mm into each isolating slot, so no coincident faces), 1.2 mm wide
    # - a void, not a wall, so the 0.6 mm nozzle is not a constraint. Clear
    # of the snap pockets (+/-X edges, y +/-12) and of every LEGO bore: the
    # x 8.95 column only has holes at y +/-4, and the x 0.95 column lies
    # outside x 4.4..11.6.
    sk = comp.sketches.add(comp.xYConstructionPlane)
    for sy in (-1, 1):
        box(sk, 4.4 * MM, 11.6 * MM, sy * 7.95 * MM, sy * 9.15 * MM)
        box(sk, 4.4 * MM, 11.6 * MM, sy * 10.65 * MM, sy * 11.85 * MM)
    profs = collection([sk.profiles.item(i) for i in range(sk.profiles.count)])
    if profs.count != 4:
        raise RuntimeError("expected 4 clip-trench profiles, found %d"
                           % profs.count)
    extrude(comp, profs, X_TRENCH_Z0, 0,
            adsk.fusion.FeatureOperations.CutFeatureOperation,
            participants=[plate_body])
    print("xiao clip trenches ok (x 4.4..11.6, 1.2 mm wide, to z %.2f)"
          % (X_TRENCH_Z0 * 10))
```

- [ ] **Step 5: Rebuild the back plate**

```bash
cd /path/to/rd03d/case/fusion_scripts && python3 run_fusion.py script 02_backplate.py; echo "exit=$?"
```

Expected: `exit=0`, ending with `xiao clip trenches ok ...` and `BackPlate bodies: 1`.

If it reports more than one body, the trenches severed the blade — check the x span covers the slots rather than butting against them.

- [ ] **Step 6: Verify**

```bash
cd /path/to/rd03d/case/fusion_scripts && python3 run_fusion.py script 90_verify.py --read-only; echo "exit=$?"
```

Expected: `VERIFY OK`, `exit=0`.

- [ ] **Step 7: Commit**

```bash
cd /path/to/rd03d && git add case/fusion_scripts/02_backplate.py case/fusion_scripts/90_verify.py && git commit -m "fix(case): XIAO clips to 1.5 mm fingers on a 1.5 mm-deeper root

A 1.0 mm finger does not print on the user's 0.6 mm nozzle, but 1.5 mm on
the old 4.30 mm lever reaches 4.1% strain - PETG's yield. Two 1.2 mm x
1.5 mm trenches either side of each finger, with the isolating slots
extended down to meet them, take the lever to 5.80 mm: 2.3% peak strain
and 1.4x the retention force, with the 0.60 mm lip and 0.34 mm grab
untouched.

Co-Authored-By: Claude Opus 5 <noreply@anthropic.com>"
```

---
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

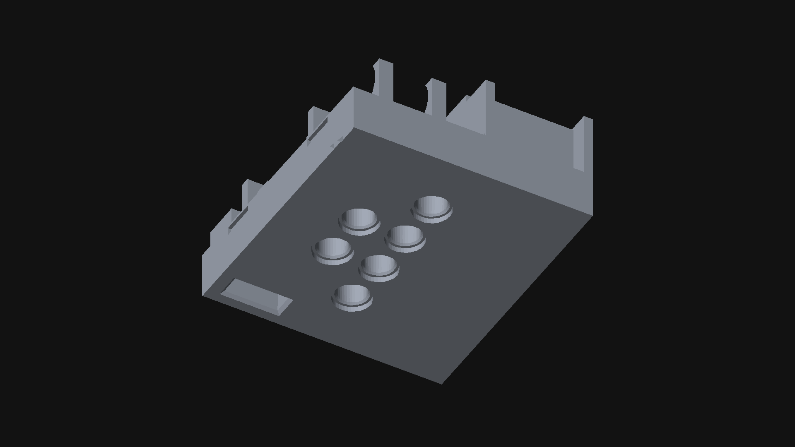
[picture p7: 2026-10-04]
video/stills/05_backplate_lego_face.png

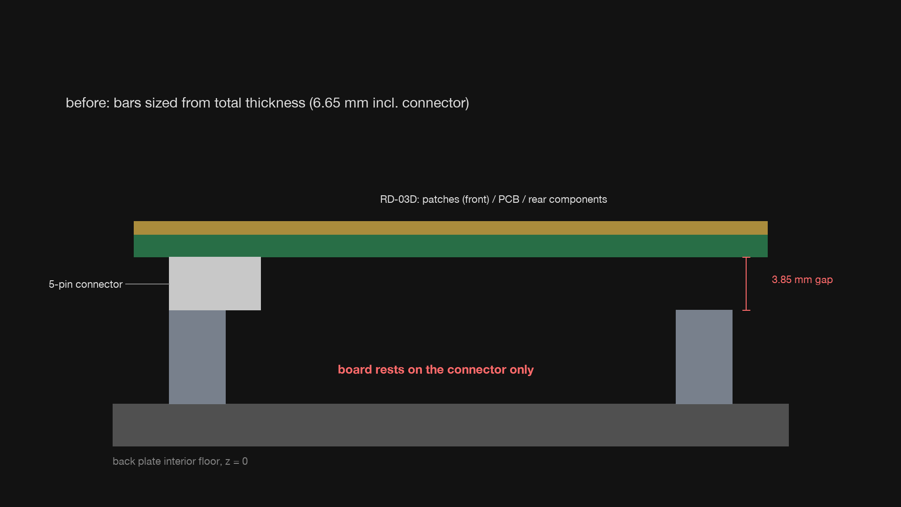
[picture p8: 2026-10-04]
video/stills/08_board_on_connector_before.png

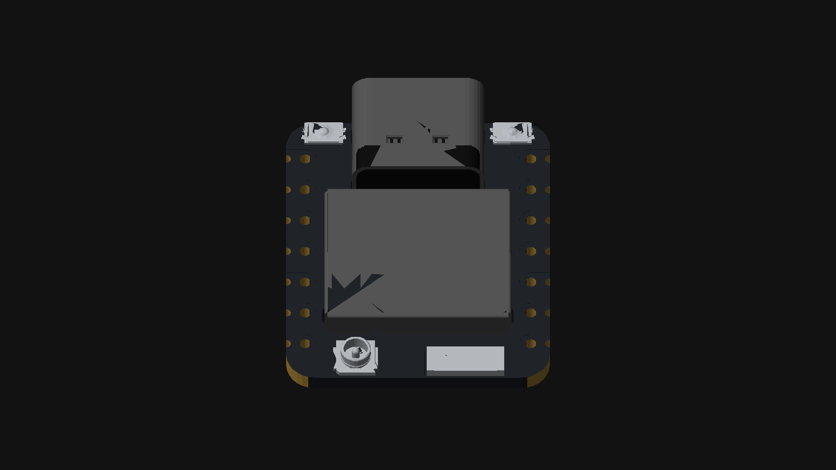
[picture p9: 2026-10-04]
video/stills/12_xiao_board_model.png

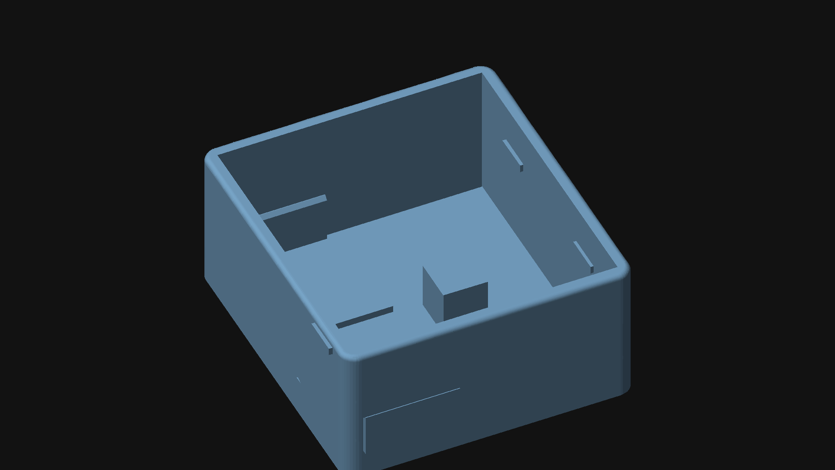
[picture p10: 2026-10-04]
video/stills/04_shell_interior_radome.png

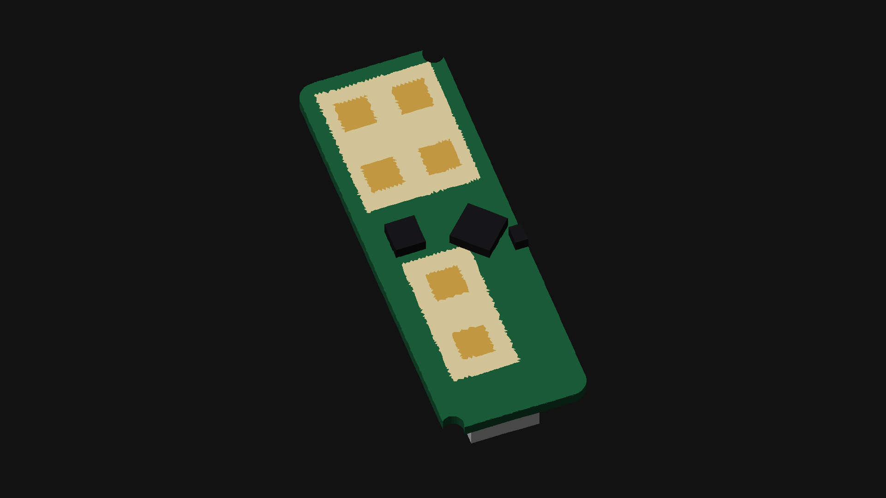
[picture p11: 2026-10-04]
video/stills/11_rd03d_board_model.png

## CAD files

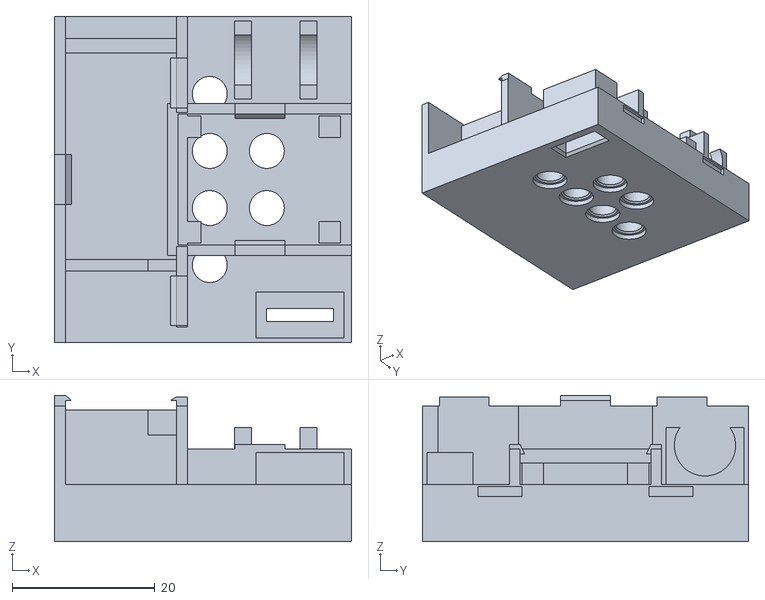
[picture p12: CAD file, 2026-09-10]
case/rd03d_case_back.stl
41.7 x 45.7 x 20.5

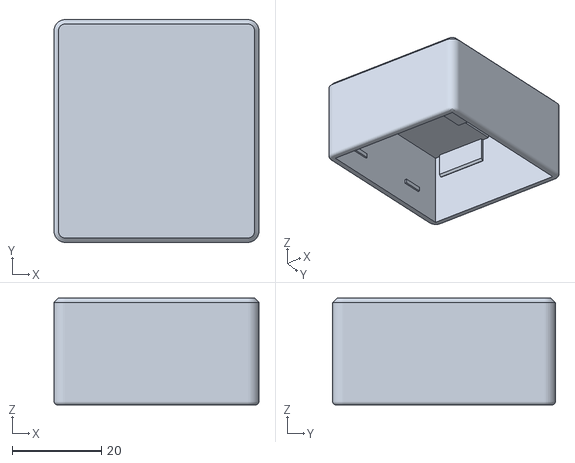
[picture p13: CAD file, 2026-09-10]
case/rd03d_case_shell.stl
46.0 x 50.0 x 24.0

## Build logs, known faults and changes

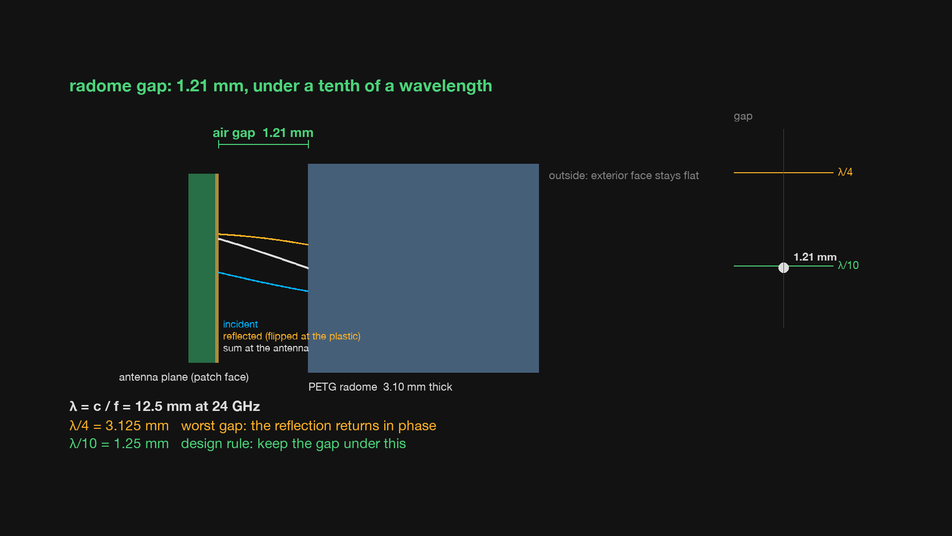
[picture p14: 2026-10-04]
video/stills/07_radome_after_fix.png

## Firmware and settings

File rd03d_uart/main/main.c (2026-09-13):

#include <inttypes.h>
#include <stdio.h>

#include "freertos/FreeRTOS.h"
#include "freertos/task.h"
#include "driver/uart.h"
#include "esp_log.h"
#include "esp_ota_ops.h"

#if CONFIG_RD03D_ENABLE_MQTT
#include "mqtt_pub.h"
#endif
#include "led.h"
#include "mqtt_throttle.h"
#include "ota_update.h"
#include "rd03d.h"
#include "web_server.h"
#include "wifi_link.h"

/* XIAO ESP32-C6, ESP side: D6 = GPIO16 (UART1 TX), D7 = GPIO17 (UART1 RX). */
#define RADAR_UART_NUM   UART_NUM_1
#define RADAR_PIN_TX     16
#define RADAR_PIN_RX     17
#define RADAR_BAUD       256000
#define UART_RX_BUF_SIZE 1024
#define STATS_PERIOD_MS  5000
#define OTA_VALID_DEADLINE_MS 90000

static const char *TAG = "rd03d";

/* Ai-Thinker multi-target detection mode command. The RD-03D powers up in
 * multi-target mode; sending this makes the mode explicit and removes the
 * sketch's need to send it (spec: firmware owns radar config). */
static const uint8_t RD03D_CMD_MULTI_TARGET[] = {
    0xFD, 0xFC, 0xFB, 0xFA, 0x02, 0x00, 0x90, 0x00, 0x04, 0x03, 0x02, 0x01,
};

static void print_frame(const rd03d_frame_t *f)
{
    char line[128];
    size_t off = 0;

    line[0] = '\0';
    for (int i = 0; i < RD03D_NUM_TARGETS; i++) {
        const rd03d_target_t *t = &f->targets[i];
        const char *sep = (i < RD03D_NUM_TARGETS - 1) ? " | " : "";
        int n;
        if (t->present) {
            n = snprintf(line + off, sizeof(line) - off,
                         "T%d: x=%dmm y=%dmm v=%dcm/s%s",
                         i + 1, t->x_mm, t->y_mm, t->speed_cms, sep);
        } else {
            n = snprintf(line + off, sizeof(line) - off, "T%d: ---%s",
                         i + 1, sep);
        }
        if (n < 0 || (size_t)n >= sizeof(line) - off) {
            break;
        }
        off += (size_t)n;
    }
    printf("%s\n", line);
}

/* A freshly-OTA'd image boots pending-verify. Mark it valid only once the
 * device is provably updatable again (WiFi up + web server running); if that
 * never happens, restart while still pending so the bootloader rolls back
 * to the previous firmware. USB-flashed images are never pending: no-op. */
static void ota_validation_task(void *arg)
{
    (void)arg;
    const esp_partition_t *running = esp_ota_get_running_partition();
    esp_ota_img_states_t state;
    if (esp_ota_get_state_partition(running, &state) != ESP_OK ||
        state != ESP_OTA_IMG_PENDING_VERIFY) {
        vTaskDelete(NULL);
        return;
    }
    TickType_t deadline =
        xTaskGetTickCount() + pdMS_TO_TICKS(OTA_VALID_DEADLINE_MS);
    while ((int32_t)(deadline - xTaskGetTickCount()) > 0) {
        if (wifi_link_is_up() && web_server_handle() != NULL) {
            ESP_ERROR_CHECK(esp_ota_mark_app_valid_cancel_rollback());
            ESP_LOGI(TAG, "firmware validated (WiFi + web server up)");
            vTaskDelete(NULL);
            return;
        }
        vTaskDelay(pdMS_TO_TICKS(1000));
    }
    if (wifi_link_is_up() && web_server_handle() != NULL) {
        ESP_ERROR_CHECK(esp_ota_mark_app_valid_cancel_rollback());
        ESP_LOGI(TAG, "firmware validated (WiFi + web server up)");
        vTaskDelete(NULL);
        return;
    }
    ESP_LOGE(TAG, "validation deadline missed - restarting to roll back");
    esp_restart();
}

void app_main(void)
{
    const uart_config_t cfg = {
        .baud_rate = RADAR_BAUD,
        .data_bits = UART_DATA_8_BITS,
        .parity = UART_PARITY_DISABLE,
        .stop_bits = UART_STOP_BITS_1,
        .flow_ctrl = UART_HW_FLOWCTRL_DISABLE,
        .source_clk = UART_SCLK_DEFAULT,
    };
    ESP_ERROR_CHECK(uart_driver_install(RADAR_UART_NUM, UART_RX_BUF_SIZE,
                                        0, 0, NULL, 0));
    ESP_ERROR_CHECK(uart_param_config(RADAR_UART_NUM, &cfg));
    ESP_ERROR_CHECK(uart_set_pin(RADAR_UART_NUM, RADAR_PIN_TX, RADAR_PIN_RX,
                                 UART_PIN_NO_CHANGE, UART_PIN_NO_CHANGE));

    ESP_LOGI(TAG, "RD-03D reader: UART%d RX=GPIO%d TX=GPIO%d @ %d baud",
             RADAR_UART_NUM, RADAR_PIN_RX, RADAR_PIN_TX, RADAR_BAUD);

    int written = uart_write_bytes(RADAR_UART_NUM, RD03D_CMD_MULTI_TARGET,
                                   sizeof(RD03D_CMD_MULTI_TARGET));
    if (written != (int)sizeof(RD03D_CMD_MULTI_TARGET)) {
        ESP_LOGW(TAG, "multi-target command short write (%d)", written);
    }
    vTaskDelay(pdMS_TO_TICKS(200));
    /* Discard the radar's command ACK so it doesn't hit the frame parser. */
    ESP_ERROR_CHECK(uart_flush_input(RADAR_UART_NUM));
    ESP_LOGI(TAG, "multi-target mode command sent");

    wifi_link_start();
    web_server_start();
    ota_update_register(web_server_handle());
    xTaskCreate(ota_validation_task, "ota_valid", 3072, NULL, 5, NULL);
    led_init();
#if CONFIG_RD03D_ENABLE_MQTT
    mqtt_pub_start();
#else
    /* No publisher in this build, so run the same movement decision purely to
     * drive the LED. Both variants then blink identically - which matters most
     * here, since the AP image is the one used for placement tests with
     * nothing attached but the board. */
    mqtt_throttle_t led_throttle;
    mqtt_throttle_init(&led_throttle, CONFIG_RD03D_MQTT_MOVE_MM);
#endif

    rd03d_parser_t parser;
    rd03d_parser_init(&parser);
    rd03d_frame_t frame;
    uint8_t buf[128];
    TickType_t last_stats = xTaskGetTickCount();

    for (;;) {
        int n = uart_read_bytes(RADAR_UART_NUM, buf, sizeof(buf),
                                pdMS_TO_TICKS(100));
        for (int i = 0; i < n; i++) {
            if (rd03d_parser_feed(&parser, buf[i], &frame)) {
                print_frame(&frame);
                web_server_send_frame(&frame, parser.dropped_bytes,
                                      parser.bad_frames);
#if CONFIG_RD03D_ENABLE_MQTT
                mqtt_pub_frame(&frame);
#else
                for (int t = 0; t < RD03D_NUM_TARGETS; t++) {
                    if (mqtt_throttle_eval(&led_throttle, t,
                                           &frame.targets[t])
                            != MQTT_THROTTLE_NONE) {
                        led_pulse();
                    }
                }
#endif
            }
        }
        if (xTaskGetTickCount() - last_stats >= pdMS_TO_TICKS(STATS_PERIOD_MS)) {
            ESP_LOGI(TAG, "link stats: dropped=%" PRIu32 " bad_frames=%" PRIu32,
                     parser.dropped_bytes, parser.bad_frames);
            last_stats = xTaskGetTickCount();
        }
    }
}

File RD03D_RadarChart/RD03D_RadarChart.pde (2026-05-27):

import processing.serial.*;

Serial serialPort;
String serialPortName = "/dev/cu.usbserial-AO003MWP"; // Leave empty to use the first available port
int baudRate = 256000; // Adjust to RD-03D baud rate if different

ArrayList<Detection> detections = new ArrayList<Detection>();
ArrayList<Byte> inputBuffer = new ArrayList<Byte>();

float maxRangeMeters = 5.0;    // Adjust to the maximum radar range you want to display
float fieldOfViewDegrees = 120; // Typical mm-wave FOV; override if the RD-03D has a different FOV
float rangeUnitScale = 0.01;    // Convert raw range units to meters (default assumes cm)
float velocityUnitScale = 0.1;  // Convert raw velocity units to m/s
int maxDetections = 120;

final int PACKET_LENGTH = 30;
final byte HEADER_A = (byte)0xAA;
final byte HEADER_B = (byte)0xFF;
final byte TAIL_A = (byte)0x55;
final byte TAIL_B = (byte)0xCC;

int packetsParsed = 0;
int parseErrors = 0;

String firmwareVersion = "Unknown";
volatile boolean configMode = true;

void setup() {
  size(900, 700);
  smooth();
  frameRate(60);
  textFont(createFont("Arial", 14));

  println("Available serial ports:");
  String[] ports = Serial.list();
  for (int i = 0; i < ports.length; i++) {
    println(i + ": " + ports[i]);
  }

  if (serialPortName.equals("")) {
    if (ports.length > 0) {
      serialPortName = ports[0];
      println("Using first available port: " + serialPortName);
    } else {
      println("No serial ports found. Connect the RD-03D or USB bridge and restart.");
    }
  }

  if (serialPortName.length() > 0) {
    serialPort = new Serial(this, serialPortName, baudRate);
    serialPort.clear();

    firmwareVersion = readFirmwareVersion();
    configMode = false;

    // Send multi-target detection command
    byte[] multiTargetCmd = {
      (byte)0xFD, (byte)0xFC, (byte)0xFB, (byte)0xFA,
      (byte)0x02, (byte)0x00, (byte)0x90, (byte)0x00,
      (byte)0x04, (byte)0x03, (byte)0x02, (byte)0x01
    };
    serialPort.write(multiTargetCmd);
    delay(200); // Wait for command to be processed
  }
}

String readFirmwareVersion() {
  byte[] enterConfig = {
    (byte)0xFD, (byte)0xFC, (byte)0xFB, (byte)0xFA,
    (byte)0x04, (byte)0x00, (byte)0xFF, (byte)0x00, (byte)0x01, (byte)0x00,
    (byte)0x04, (byte)0x03, (byte)0x02, (byte)0x01
  };
  byte[] readVersion = {
    (byte)0xFD, (byte)0xFC, (byte)0xFB, (byte)0xFA,
    (byte)0x02, (byte)0x00, (byte)0x00, (byte)0x00,
    (byte)0x04, (byte)0x03, (byte)0x02, (byte)0x01
  };
  byte[] exitConfig = {
    (byte)0xFD, (byte)0xFC, (byte)0xFB, (byte)0xFA,
    (byte)0x02, (byte)0x00, (byte)0xFE, (byte)0x00,
    (byte)0x04, (byte)0x03, (byte)0x02, (byte)0x01
  };

  serialPort.write(enterConfig);
  byte[] enterAck = readConfigResponse(500);
  if (enterAck.length == 0) {
    println("No response to enter-config command.");
    serialPort.write(exitConfig);
    readConfigResponse(200);
    return "Unknown";
  }

  serialPort.write(readVersion);
  byte[] versionAck = readConfigResponse(500);

  serialPort.write(exitConfig);
  readConfigResponse(200);

  return parseFirmwareVersion(versionAck);
}

// Read one FD FC FB FA ... 04 03 02 01 config frame, returning just the payload
// (the bytes between the 2-byte length field and the 4-byte footer).
byte[] readConfigResponse(int timeoutMs) {
  ArrayList<Byte> buf = new ArrayList<Byte>();
  int start = millis();
  while (millis() - start < timeoutMs) {
    while (serialPort.available() > 0) {
      int b = serialPort.read();
      if (b < 0) break;
      buf.add((byte) b);
    }
    for (int i = 0; i + 10 < buf.size(); i++) {
      if (buf.get(i) == (byte)0xFD && buf.get(i+1) == (byte)0xFC &&
          buf.get(i+2) == (byte)0xFB && buf.get(i+3) == (byte)0xFA) {
        int len = (buf.get(i+4) & 0xFF) | ((buf.get(i+5) & 0xFF) << 8);
        int frameEnd = i + 6 + len + 4;
        if (buf.size() >= frameEnd) {
          if (buf.get(frameEnd - 4) == (byte)0x04 && buf.get(frameEnd - 3) == (byte)0x03 &&
              buf.get(frameEnd - 2) == (byte)0x02 && buf.get(frameEnd - 1) == (byte)0x01) {
            byte[] payload = new byte[len];
            for (int j = 0; j < len; j++) payload[j] = buf.get(i + 6 + j);
            return payload;
          }
        }
      }
    }
    delay(10);
  }
  return new byte[0];
}

// Payload layout for the 0x0000 ACK:
//   [0..1] ack word (0x0100), [2..3] status, [4..5] fw type,
//   [6..7] major/minor (BCD-ish), [8..11] revision (LE, often date-coded)
String parseFirmwareVersion(byte[] payload) {
  if (payload == null || payload.length < 12) {
    return payload != null && payload.length > 0 ? hexDump(payload) : "Unknown";
  }
  int status = (payload[2] & 0xFF) | ((payload[3] & 0xFF) << 8);
  if (status != 0) return "Error 0x" + hex(status, 4);
  int minor = payload[6] & 0xFF;
  int major = payload[7] & 0xFF;
  long rev = ((long)(payload[11] & 0xFF) << 24) | ((long)(payload[10] & 0xFF) << 16) |
             ((long)(payload[9]  & 0xFF) << 8)  |  (long)(payload[8]  & 0xFF);
  return "V" + major + "." + nf(minor, 2) + "." + hex((int)rev, 8);
}

String hexDump(byte[] b) {
  StringBuilder sb = new StringBuilder();
  for (int i = 0; i < b.length; i++) sb.append(hex(b[i], 2));
  return sb.toString();
}

void draw() {
  background(18);
  drawCartesianBackground();
  drawDetections();
  drawHud();
}

void drawCartesianBackground() {
  pushMatrix();
  translate(width * 0.5, height * 0.55);

  float size = min(width, height) * 0.65;
  float half = size * 0.5;

  stroke(100, 180);
  strokeWeight(1);
  noFill();
  rect(-half, -half, size, size);

  int gridLines = 10;
  for (int i = 1; i < gridLines; i++) {
    float pos = lerp(-half, half, i / (float)gridLines);
    stroke(80, 140);
    line(pos, -half, pos, half);
    line(-half, pos, half, pos);
  }

  stroke(200);
  strokeWeight(2);
  line(-half, 0, half, 0);
  line(0, -half, 0, half);

  fill(200);
  noStroke();
  textAlign(RIGHT, TOP);
  text("Y", -half + 16, -half + 8);
  textAlign(LEFT, BOTTOM);
  text("X", half - 16, half - 8);

  popMatrix();
}

void drawDetections() {
  ArrayList<Detection> snapshot;
  synchronized(detections) {
    snapshot = new ArrayList<Detection>(detections);
  }

  float chartSize = min(width, height) * 0.65;
  float half = chartSize * 0.5;
  float maxRangeMm = maxRangeMeters * 1000.0;

  pushMatrix();
  translate(width * 0.5, height * 0.55);

  int[] targetColors = {color(0, 180, 255), color(0, 220, 120), color(255, 180, 40)};

  for (Detection d : snapshot) {
    if (d.valid == 0) continue;

    float px = map(d.x, -maxRangeMm, maxRangeMm, -half, half);
    float py = map(-d.y, -maxRangeMm, maxRangeMm, -half, half);

    int col = targetColors[(d.id - 1) % targetColors.length];
    stroke(col);
    fill(col, 180);
    ellipse(px, py, 1, 1);

    //fill(255);
    //textAlign(CENTER, CENTER);
    //textSize(12);
    //text("T" + d.id, px, py - 18);
  }

  popMatrix();
}
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

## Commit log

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2026-09-06 feat(rd03d_uart): live radar chart web page
    Cap inbound WS frame length in ws_get's drain path (128 bytes) per
    Task 4 code review; the previous malloc(frame.len) was unbounded and
    client-controlled.
2026-09-06 feat(rd03d_uart): two-slot OTA partition table on 4MB flash
    [partitions.csv]
2026-09-06 fix(rd03d_uart): latch OTA guard through reboot; final validation re-check
    [main.c]
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2026-09-07 feat(rd03d_uart): publish throttled target events to MQTT
    Cross-task race fix (Task 1 review amendment): throttle reset on
    reconnect is deferred to the radar task via s_reset_pending instead of
    running on the esp-mqtt event task, since mqtt_throttle is documented
    NOT thread-safe. Also documents the eval() caller contract and adds
    three regression tests (threshold=0, flapping target, reset-while-
    absent) to test_mqtt_throttle.c.
    [main.c]
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2026-09-07 fix(case): driver treats bare error responses as failure; decode before write
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2026-09-07 feat(case): BackPlate component with board bays and snap grooves
    Adaptations from the plan's starting code: snap-groove sketch centered on
    the plate edge for the prescriptive 0.6 mm depth (as given it cut 0.9 mm),
    and a final intersect-extrude trims the bay fences to the plate outline
    (the radar fence ring and XIAO fence bars as drawn overhung the
    41.7 x 45.7 mm plate into the shell-wall space).
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2026-09-07 feat(case): FrontShell with radar window, USB notch, snap bumps
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2026-09-07 fix(case): restrict cut participation to shell body; blind snap pockets
2026-09-07 feat(case): import boards, position in bays, interference-check
    Radar flipped 180 about Z so the RX patch array sits under the window
    (no window flip needed); radar fence +X wall notched over the XIAO
    footprint - the prescriptive bay centers leave only 0.72mm between the
    boards, so the full-height wall passed through the XIAO board. Zero
    board-vs-case and case-vs-case interference pairs; only sub-0.001cm3
    vendor-model self-pairs inside the XIAO's USB connector remain.
2026-09-07 feat(case): export print STLs and document the case
    [rd03d_case_back.stl, rd03d_case_shell.stl]
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2026-09-07 feat(case): LEGO Technic mounting interface (8mm plate, 6-hole grid)
    [rd03d_case_back.stl, rd03d_case_shell.stl]
2026-09-07 docs(case): param-reset caution; sync spec plate thickness
2026-09-07 feat(case): soften exterior shell edges for hand comfort
    [rd03d_case_shell.stl]
2026-09-07 feat(case): interior radar window pocket - smooth exterior, clean chamfer loop
    [rd03d_case_shell.stl]
2026-09-07 fix(case): remove sub-nozzle fence walls; radar Y-restraint via shell ribs
    [rd03d_case_back.stl, rd03d_case_shell.stl]
2026-09-07 fix(case): flat back (tape recess deleted); rib clearance and lead-in chamfer
    [rd03d_case_back.stl, rd03d_case_shell.stl]
2026-09-08 fix(case): radar bears on PCB not connector; TX window; XIAO hold-down boss
    [rd03d_case_back.stl, rd03d_case_shell.stl]
2026-09-08 docs(case): correct shield height and boss gap to measured 6.25/0.15 mm
2026-09-09 fix(case): radome to 1.2mm antenna gap; radar and XIAO retention clips
    [rd03d_case_back.stl, rd03d_case_shell.stl]
2026-09-09 fix(case): longer XIAO clip lever; extra lid clearance on the +X radar clip
    [rd03d_case_back.stl]
2026-09-10 fix(case): three radar clips, no relief slots; XIAO slots retained
    [rd03d_case_back.stl]
2026-09-10 docs(case): spec USB-C base jack, cap cradle, wire routing
    Back-plate through-slot with an internal 45 deg seating ramp pair at
    z=2.58 (the jack's 10.58 mm metal shell wedges to a stop there), a
    1.2 mm C-clip saddle for the 100 uF cap in the +Y band, fence notches
    for the 5V/GND pair, and the fence's open +X side as the cap's route.
    Records why the user's chosen "Option B" (fully recessed jack) was not
    built: measured at 14.42 mm the part is longer than the 8 mm plate and
    the 14.0 mm cavity, and its only step faces inward, so B's plate-shelf
    retention does not exist. Pull-out is adhesive by necessity.
    Bundled: shell USB notch deleted (base jack replaces it), interior LEGO
    counterbores dele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
2026-09-10 docs(case): implementation plan for the USB-C base jack
    Eight tasks, each a test-first loop against a new read-only probe script
    (90_verify.py, pointContainment assertions run through the MCP driver):
    harness, XIAO clip rework, interior counterbore deletion, jack slot +
    collar + ramps, cap cradle, fence notches, shell notch deletion, export
    and handover.
2026-09-10 test(case): read-only geometry verifier for the Fusion model
    Point-containment probes over BackPlate and FrontShell, run through the
    MCP driver with --read-only. Baseline covers the plate core, a LEGO bore,
    the radar clip wall, both XIAO fence walls and the shell cavity.
2026-09-10 fix(case): XIAO clips to 1.5 mm fingers on a 1.5 mm-deeper root
    A 1.0 mm finger does not print on the user's 0.6 mm nozzle, but 1.5 mm on
    the old 4.30 mm lever reaches 4.1% strain - PETG's yield. Two 1.2 x 1.5 mm
    trenches either side of each finger, with the isolating slots extended down
    to meet them, take the lever to 5.80 mm: 2.3% peak strain and 1.4x the
    retention force, with the 0.60 mm lip and 0.34 mm grab untouched.
    Plate volume 16.637 -> 16.614 cm3; hand-calculated net -22 mm3 (trenches
    -52, dropped thinning +39, deeper slots -9) against -23 measured.
    Also corrects two mis-specified probes authored in the plan: the lip probe
    sat at z=4.25, inside the deliberate 0.10 mm float gap bel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
2026-09-10 docs(case): repair duplicated tail in the implementation plan
    An index() on a non-unique marker while backfilling the README and memory
    text spliced the document from Task 2's commit step onward, duplicating
    Tasks 3-8 and orphaning Task 8's own commit and report steps. The two
    copies were byte-identical, so removing the second loses nothing. Scripts
    and model were never affected.
2026-09-10 fix(case): delete the interior LEGO counterbores
    A Technic pin is only ever inserted from the back, so the six 6.4 x 0.9
    recesses on the interior face served nothing and fell where the new
    capacitor cradle and clip trenches want flat floor. Rear counterbores and
    the rear entry chamfers are unchanged.
2026-09-10 feat(case): USB-C base jack slot, collar and seating ramps
    9.33 x 3.42 through-slot at (13.6, -19.0) with the mouth flush at the back
    face; 6.42 mm of the 14.42 mm jack protrudes into the free -Y band beside
    the XIAO. A 1.5 mm collar carries 45 deg ramps at z=2.58 - where the
    10.58 mm metal shell ends - that wedge the shell to a stop and take the
    plug-insertion load, narrowing to a 1.82 mm channel for the PCB tail so
    the pads stay solderable above the collar.
    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
2026-09-10 feat(case): capacitor cradle in the +Y band
    Two 1.2 mm C-clip saddle ribs at x 3.0 and 12.8 with the cap's cylinder
    bored through them - 1.2 mm arms at the equator, 7.0 mm mouth at z=8.0 so
    the 8.2 mm cap snaps down past its widest point. Laid on its side rather
    than standing: 12 mm upright in a 14 mm cavity points the leads at the lid,
    and the footprint only fits the -Y band beside the jack by ~0.1 mm.
    Rib x positions clear the +Y clip trench by 0.6 mm; lead end faces +X,
    where the XIAO fence is already open as a wire channel.
    The bore is the only feature here that does not sketch on XY. Its plane
    reports uDirection = world +Y / vDirection = world +Z, but the sketch
    Fusion creates on that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
2026-09-10 docs(case): record the non-XY sketch-basis trap in the plan
    Task 5's bore code assumed a sketch inherits its plane's uDirection/
    vDirection. It does not: on a YZ-parallel plane the sketch picks
    u = world -Z, v = world +Y, so the circle landed below the plate and the
    Cut silently removed nothing while still reporting success. Marked the
    block as superseded and recorded the modelToSketchSpace rule.
2026-09-10 feat(case): wire notches in both XIAO fence walls
    3.5 x 2.5 mm notch at x 14.5..18.0, outboard of the XIAO's 5V/GND pads, so
    the jack's pair drops straight down instead of being pinched between the
    board edge and the wall. Cut in both walls so a mirrored board costs
    nothing; clear of the clip fingers at x 4.5..11.5.
2026-09-10 feat(case): delete the shell's side USB notch
    The base jack replaces it entirely. Removes the notch cut, its
    edge-softening pass, and the permissive 8..10 back-rim edge guard - with
    the notch gone the rim is exactly one 8-edge loop.
    Consequence: the XIAO's own USB-C is no longer reachable with the case
    closed. Serial console and USB reflash need the lid unclipped; OTA is
    unaffected. usbClear becomes a dead parameter, left in place because
    re-running 01_setup.py would reset user-tuned values.
2026-09-10 feat(case): export STLs and document the base-jack build
    Re-exported both parts after the jack, cradle, notch and clip changes.
    README covers jack assembly order, the 5.1k CC pulldowns, cap orientation,
    the wire route, and that the XIAO's USB-C is no longer reachable with the
    case closed.
    Clean rebuild from the committed scripts passes: VERIFY OK, plate volume
    16.729 cm3, shell volume 13.664 cm3.
    Mesh stats (mm; the STLs export in mm, so the plan's harness x10 factor
    prints them ten times too large):
    rd03d_case_back.stl 3224 tris x -20.85..20.85 y -22.85..22.85 z -8.00..12.50
    rd03d_case_shell.stl 2112 tris x -23.00..23.00 y -25.00..25.00 z -8.00..16.00
    Back-plate z tops out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
    [rd03d_case_back.stl, rd03d_case_shell.stl]
2026-09-10 docs(case): drop the spurious x10 in the plan's STL measurement snippet
    Fusion writes STL in millimetres, not centimetres, so the snippet reported
    the back plate as 417 x 457 mm. Confirmed against the previously committed
    STL, whose known-good z range was -8..12.50.
2026-09-10 fix(case): clear the LEGO bores; correct the jack fitting order
    Final review of feat/case-usb-jack found two print-affecting geometry bugs
    and three documentation errors.
    Geometry (02_backplate.py):
    - Cradle ribs moved x 3.0/12.8 -> 5.0/14.8. The x=3.0 rib (footprint
    x 2.40..3.60, z 0..8) sat over the Technic through-bore at (0.95, +12),
    which reaches x 3.40 - a 1.00 mm overlap across 3.20 mm of y, roofing
    ~11% of that bore's interior mouth for the rib's full height. A pin
    pushed in from the back would have bottomed out on it, costing one of
    the six mount holes, discoverable only after printing. The 9.8 mm rib
    span is unchanged, so the capacitor sits identically (centred at x 9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
    [rd03d_case_back.stl]
2026-09-10 fix(case): delete XIAO clip slots and root trenches - user print report
    The user printed the slotted-and-trenched XIAO clips, handled the part,
    and reported them "very wimpy - barely holding it in", then asked for the
    slots and the trench to be removed. Physical evidence beats the strain
    calculation the earlier design optimised for.
    02_backplate.py:
    - step 8b passes NO_SLOTS, so clip() skips the isolating slot cuts
    - step 8c (four clip-root trenches) deleted outright: with no slots the
    finger is not a cantilever, so there is no root to lengthen
    - X_TRENCH_Z0 / X_SLOT_Z0 removed as dead (X_THIN is already 0.0, so
    clip() never reads slot_z0)
    - X_RAISE_Z0 / X_TOP_Z / X_LIP_Z /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
    [rd03d_case_back.stl]
2026-09-10 feat(case): cut a radar cable exit through the +X bay wall
    The user photographed the assembled plate: the RD-03D's 4-wire connector
    cable leaves the connector heading -Y, off the end of the board, with
    nowhere to go. The connector pocket is sealed on three sides - the two
    bay walls at +/-X and crossbar A, which spans the full bay width at
    y -12.8..-11.2 from the floor up to the PCB rear face it supports. No gap
    over it, because the board is what rests on it.
    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
    [rd03d_case_back.stl]
2026-09-10 feat(case): slot crossbar A so the radar cable routes under the board
    The user's proposal, and better than the corner notch in bfb65f4: come up
    through the rib that seals the connector pocket rather than squeezing round
    the outside. Crossbar A spans the full bay width at y -12.8..-11.2 from the
    floor to the PCB rear face, so a 4 mm full-height slot at x -11..-7 opens
    the pocket into the bay, leaving the bar as 8.3 + 3.3 mm segments that each
    still butt into a wall and bear on the board.
    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
    [rd03d_case_back.stl]
2026-09-10 fix(case): tunnel the crossbar slot; thicken the capacitor ribs
    Both user calls after handling the print.
    Crossbar A: the full-height slot becomes a 3.5 mm tunnel hard against the
    +X wall. The bar keeps its full 15.6 mm of bearing on the PCB rear instead
    of splitting into segments, and the wires emerge hugging the wall they then
    run along to the step-4b notch. 3.5 x 4.0 mm passes four ~1.5 mm wires
    stacked 2x2; the 4 mm bridge prints unsupported.
    Cradle ribs: the printed ones look fragile, so RIB_W (width along X) doubles
    1.2 -> 2.4 mm - four perimeters on a 0.6 nozzle instead of two. RIB_ARM (the
    radial arm) stays 1.2 and is now a separate constant: it sets the rib's Y
    extent, and at 1.5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
    [rd03d_case_back.stl]
2026-09-10 fix(case): move the crossbar A cable notch to the top of the bar
    User's call: a top-opening notch prints with no support at all - nothing
    spans the gap, the bar simply stops at z 6.96 - where the base tunnel left
    a 4 mm bridge. It also suits the cable, which leaves a connector whose
    underside is at z 6.70: the wires run straight through at that height
    instead of diving to the floor and climbing back, and once the board is
    clipped down they are captured between the notch floor and the PCB rear.
    Cost, recorded in the code: 4.0 mm out of the bar's 15.6 mm bearing line,
    leaving 11.6 mm on the -X side. The board is still carried at two y stations
    and held by three clips and the lid.
    Plate volum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
    [rd03d_case_back.stl]
2026-09-10 fix(case): delete the XIAO fence wire notches
    They were defensive and now cost more than they give. The wall top is z 5.00
    and the XIAO's pads are at 4.20, so a wire laid over the bar climbs 0.8 mm
    with ~9 mm of headroom - all the notch ever saved. Against that, the clip
    rework removed the isolating slots, so the finger's stiffness now comes from
    being continuous with the wall either side of it, and a notch 3 mm past the
    finger's end at x 11.5 sat in exactly that load path.
    No other consumer: the radar cable crosses above the board via the step-4b
    notch, and the capacitor's leads go over a bar.
    check_fence_notches becomes check_fence_walls_continuous and now asserts the
    opposite of what it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
    [rd03d_case_back.stl]
2026-09-11 docs(rd03d_uart): spec the SoftAP firmware variant
    The user needs the prototype node working on a work site that forbids
    unregistered devices on its WiFi. The XIAO becomes its own WPA2 access
    point; the laptop joins it directly. MQTT compiles out - no broker there.
    One codebase with a RD03D_NET_MODE Kconfig choice rather than a divergent
    branch, so radar/chart/OTA fixes land in both images at once. The AP image
    builds with its own sdkconfig and build dir.
    Records the trap this would otherwise hit: main.c gates the OTA
    rollback-cancel on wifi_link_has_ip(), set only by IP_EVENT_STA_GOT_IP,
    which never fires in AP mode. Every OTA'd image would roll back while USB
    flashing kept working - so i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
2026-09-11 docs(rd03d_uart): implementation plan for the SoftAP variant
    Six tasks: rename wifi_link_has_ip first and alone, Kconfig, the second
    build configuration, the SoftAP branch, compiling MQTT out, then hardware
    verification.
    The rename leads because the old name is what hides the AP-mode rollback
    bug. Task 4's test is a deliberate failing build - a 5-character PSK must
    be rejected by the static assert before the real one goes in - since a
    silent WPA2 failure on a headless device is what the assert exists to
    prevent. Task 6 hands the laptop-side checks to the user, because this Mac
    cannot join the AP without dropping its own network.
2026-09-11 docs: fix a glued code fence in the softap plan
    Chunked write left Task 3's closing fence on the same line as the last
    command, which would render the rest of the step as code.
2026-09-11 chore: gitignore rd03d_uart/build.ap/
    The SoftAP build tree was uncovered - only rd03d_uart/build/ was ignored -
    so a git add -A would have staged a whole build directory. Caught during
    task 3.
2026-09-11 feat(rd03d_uart): SoftAP branch in wifi_link
    WIFI_MODE_AP with WPA2-PSK, channel and SSID from Kconfig, max 4 clients,
    fixed 192.168.4.1 with the ESP running DHCP for joining laptops. mDNS is
    registered in both modes and advertises over whichever interface is up.
    wifi_link_is_up() is set on WIFI_EVENT_AP_START. Without that, main.c's OTA
    validation would never see the network as up in AP mode and would roll back
    every wirelessly-updated image after 90 s - while USB flashing kept working,
    because a full flash erases otadata and never arms rollback.
    A compile-time assert rejects a PSK under 8 characters; WPA2's minimum, and
    otherwise esp_wifi_set_config fails at runtime on a headless device.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
2026-09-11 docs: correct task 4's expected build outcome in the softap plan
    The note claimed the AP image would still build with MQTT compiled in. It
    does not: task 3 turns RD03D_ENABLE_MQTT off, and the broker symbols are
    depends-on, so they are undefined and mqtt_pub.c fails to compile. What the
    step really proves is that wifi_link.c compiles clean in AP mode.
    Recorded that task 5 is therefore load-bearing for the AP build rather than
    a cleanup, and that build.ap/ holds a stale artifact until task 5 rebuilds.
2026-09-11 docs: discover the serial port instead of hardcoding it
    The plan named /dev/cu.usbmodem1101 in three places - that is the assembled
    node's port. The prototype enumerates as /dev/cu.usbmodem101, so task 6
    would have failed to find a board, and on another day could have flashed
    the wrong one.
2026-09-13 feat(rd03d_uart): flash the user LED on every published event
    The node is deployed where a browser is inconvenient, so give it a visual
    heartbeat: one ~40 ms pulse per event that actually reaches the broker, which
    makes the LED a literal echo of what Node-RED receives rather than a vague
    activity light. Pulsing only on a successful enqueue means it says "a message
    went out", not "we thought about sending one".
    GPIO15 active-low is the XIAO ESP32-C6's user LED, but that is board wiring
    and unverified here - the red LED the user can see may instead be the battery
    charge indicator, which is wired to the charger IC and unreachable from
    software. Hence RD03D_LED_GPIO (-1 disables), RD03D_LED_ACT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
    [led.c, main.c]
2026-09-13 feat(node-red): set the stair-light ZONE from the walk test
    Measured 2026-09-12: downstairs approach, up the stairs, exit top, return,
    back down. 474 chart points over 46 s. Both approaches funnel through a gate
    at x ~ -660, y ~ 1030-1280, so the bounds are built around that.
    xMin -2000 deliberately excludes the x -2090 leg walking off to the workshop,
    so leaving does not hold the light on. yMax 4000 lights the stairs ~7 s
    before the gate; 5000 would buy ~2 s more at the cost of reacting to movement
    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
2026-10-04 Correct three statements in the narration and README
    The video said the access-point image rolled back after every update. It
    never did: the trap was found while writing the design note and the fix was
    in the first version of the AP code. The narration and the on-screen text
    now say so.
    The board-on-connector item said the author measured the rear profile. He
    spotted the problem in the Fusion model; the agent probed the vendor model
    and moved the bars. Same correction in the README.
    The antenna orientation item now says the portrait assumption was the
    author's and the agent caught it, and the section title no longer blames
    every item on the agent.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
2026-10-13 Hackaday close keeps the credit line; teleprompter generated from the narration
    The self-narrated close had dropped the sentence crediting the agent for the
    script and video, which shot_07 cues its last end-card line on, so the
    Hackaday variant could not render. The sentence is back, matching the base
    narration.
    teleprompter.html is now written by make_teleprompter.py from the narration
    text, so the prompter cannot drift from the script again. The regenerated
    pages carry the corrected statements (access-point rollback, who caught the
    connector seating, the portrait request).
2026-10-13 Hackaday subtitles re-timed to the re-recorded shots 1, 2, 3, 5, 6 and 7
    Those shots were recorded again from the corrected script (shots 2 and 6
    also fixed slips), so the cue text and timings now match the audio. The cut
    runs 9:23.
2026-11-01 PIR companion: Panasonic EKMC1603111 beside the radar, plate rev, node name
    A PIR motion sensor joins the RD-03D on the same node and in the same
    stair-light flow, as an early-warning companion rather than a replacement.
    Firmware (rd03d_uart): RD03D_ENABLE_PIR / RD03D_PIR_GPIO / RD03D_PIR_HOLD_MS;
    ISR -> queue -> task -> gate with a hold window (pir_gate.c, host-tested);
    <name>/pir events carry the event count, SNTP time and the nearest radar
    target; retained <name>/pir/state. SNTP clock (clock_ms.c). The PIR is
    compiled out of the access-point image. RD03D_NODE_NAME makes the mDNS
    hostname and MQTT prefix configurable so a second board can live on the
    same network (the spare was built as r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
